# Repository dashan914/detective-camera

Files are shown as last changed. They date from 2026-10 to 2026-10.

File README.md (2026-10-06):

# 侦探相机 · Detective Camera

**把一张日常照片，变成一份可以带走的微型案卷。**

> **许可边界**：MIT 仅覆盖项目自有代码，CC BY 4.0 仅覆盖原创文档与外壳设计。仓库及历史中的试验配音、文学摘录和来源待确认的 ES8311 驱动，不属于这两项授权；其公开分发权尚未核实。公开可访问不代表这些素材可以自由复用、再分发或用于商业用途，请在使用前另行确认权利。第三方依赖保留原许可，详见 [许可声明](NOTICE.md)。

侦探相机是一台结合 AI、实体交互与数字制造的创作相机。按下快门后，它观察照片中的物件与细节，以真实可见的线索为起点，虚构一桩离奇、有趣、但符合现实因果的微型案件，再通过屏幕表情、侦探式语音和热敏打印，把这次观察变成一份纸质报告。

它不是用来判断现实真相的侦查设备，而是一个让人重新注意日常、参与叙事的创作搭档：一个杯子、一件衣服、一张工作台，都可能成为故事的开始。

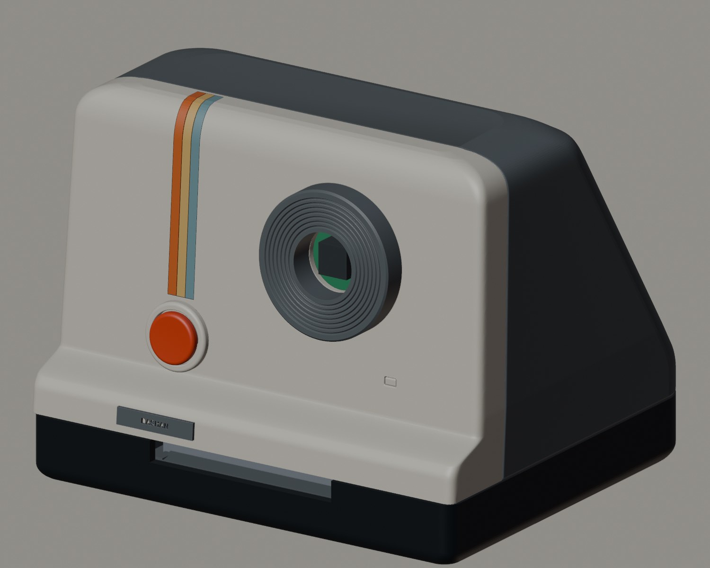
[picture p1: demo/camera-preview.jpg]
侦探相机外观


## 在线体验

[打开侦探相机交互演示](https://ai3dclass.cn/dashan/detective-camera/)

点击机身快门，体验侦探说话、顶部屏幕表情变化与案件出纸的过程；也可以拖动观察相机外观、打开字幕或阅读案卷。

网页使用固定案例展示交互，不连接实机，也不拍摄或上传观众的照片。真实相机则使用现场拍下的照片生成案件。

## 为什么做它

许多 AI 体验停留在输入框与屏幕里。我们想把它变成一个真实的小物件：能拿在手里、能表达反应，也能吐出一份纸质结果。让照片不只是被识别，而是成为一次有角色、有悬念、有反馈的互动。

创作者决定体验、硬件结构与叙事尺度，AI 辅助代码编写和方案迭代。项目关注的不是训练一个新的基础模型，而是如何把现成的模型能力、硬件和人的创意组织成完整体验。

## 一次使用会发生什么

1. **观察**：按下快门，拍摄眼前场景，记录物件、位置和状态。
2. **思考**：等待分析时，屏幕出现侦探表情，本地语音以观察和思考的口吻回应。
3. **推理**：以照片事实为依据设定案件，用一致的目标、行动和结果还原故事。
4. **出卷**：将照片、线索与推测打印成案卷；可选语音讲述同一个案件。

## 案卷 001｜衣服真正的主人

我发现衣服的肩膀上，总有两个鼓包。于是，我请它调查一下。没想到，它先调查了我。

现场线索：衣服肩部有两处凸起，位置正好对应衣架的两端。

> 衣架穿了它太久，这件衣服早就记住了衣架的样子。\
> 衣服真正的主人是衣架。\
> 而你，极有可能是个小偷。

第一次使用，它就把我从侦探变成了嫌疑人。

## 项目特色

- **照片事实与虚构故事分离**：先记录可见线索，再组织案情；不把虚构身份、动机说成已证实的事实。
- **把等待设计成表演**：语音、表情与打印状态配合，让分析延迟成为角色思考的一部分，而不是静止的加载页。
- **实体结果可以带走**：384 点热敏案卷把交互从屏幕延伸到纸上。
- **从软件到相机身体**：提供设备源码、后端、提示词、测试、网页演示和 V33 可编辑外壳/27 个 STL。

## 系统组成

ESP32-S3 负责拍照、快门、屏幕、语音播放和打印；Python 后端负责模型调用、结果校验、任务队列、票面与可选 TTS。模型输出文字/JSON，票面图片来自实拍照片的黑白处理，不是 AI 生成图片。

诗歌/文学匹配保留为附属功能，侦探相机是主线。

## 项目文件

| 目录 | 内容 |
| --- | --- |
| `competition/` | 项目简介、参赛展示脚本与证据清单 |
| `firmware/` | ESP32-S3 相机、快门、显示、音频、打印与配网源码 |
| `backend/` | 导演台、模型配置、案件生成/校验、渲染与测试 |
| `hardware/` | V33 装配、27 个 STL、结构预览与设计核验 |
| `demo/` | 三维交互、固件动画和固定案卷演示 |
| `voice_pack_12/` | 快门、思考与打印阶段的语音文件及命名说明 |
| `docs/`、`tools/` | 开发、接线、部署、验证与维护工具 |

## 制作与开发

- [本地开发指南](docs/DEVELOPMENT.md)：在自己的电脑上运行演示与导演台。
- [硬件与接线](docs/HARDWARE.md)、[原型物料清单](hardware/BOM.md)、[固件编译](firmware/README.md)。
- [外壳与打印文件](hardware/README.md)、[部署说明](docs/RESTORE.md)。
- [项目介绍](competition/PROJECT_BRIEF.md)、[展示指南](competition/DEMO_GUIDE.md)。

侦探相机用于互动创作，案情属于虚构，不用于现实侦查、身份判断或执法。实际硬件的验证范围见 [验证记录](docs/BACKUP_2026-10-04.md)。

## 许可与贡献

自有代码采用 [MIT](LICENSE)，原创文档与外壳设计采用 [CC BY 4.0](LICENSE-CONTENT.md)。第三方组件与素材的具体范围见 [许可声明](NOTICE.md)。

[贡献指南](CONTRIBUTING.md) · [隐私说明](docs/PRIVACY.md) · [安全说明](SECURITY.md)

维护署名：DASHAN / `dashan914`。

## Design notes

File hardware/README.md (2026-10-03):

# V33 外壳归档

自有 CAD/STL 和原创结构说明采用 CC BY 4.0，署名 `DASHAN (dashan914)`；第三方硬件/商标不因此获得授权。
物料索引与待实测项见 `BOM.md`。

`cad/DASHAN_V33.blend`：可编辑装配副本，保留 67 个网格物件（含辅助/试配样件）和 27 个打印件；从新场景导入几何，删除外部库记录、自定义元数据、图片与嵌入脚本。文件位置元数据改为中性相对名称并压缩保存，重新载入核验所有网格和变换与原稿一致。未改原装配或零件尺寸。使用 Blender 5.2.2 核验。

`stl/`：27 个独立零件，单位 mm。分别导入切片软件，按平台分盘，检查朝向、支撑和接触面。不要把网页 GLB 当作打印模型。

V33 基于 V30：只更换底座，正面看左侧靠后预留 USB-A 孔，右侧保持完整。
孔 13 × 6 mm、圆角 R1；孔中心距底面 11 mm、距最后端 13 mm。
`v33-check.json` 是原设计的开孔核验记录，不代表整机实物装配验收。
`previews/base-usb-left.png` 为开孔预览。

屏幕载架为 `33_LCD183_carrier.stl`，屏幕嵌入机身顶部开口。
接口模块固定座尚未设计，需实际试装；螺丝孔与螺丝长度也需按实物复核，不能将旧讨论视为全部验证完成。
USB 接口不能直接接电池电芯。电源接线说明见 `../docs/HARDWARE.md`。

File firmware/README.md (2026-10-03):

# 侦探相机固件

自有源码采用 MIT，但第三方库与未核实驱动不受该许可覆盖。
ESP32-audioI2S 3.4.7 为 GPL-3.0；分发与其组合的固件前需完成对应源码和许可证合规检查。
当前 ES8311 驱动的来源记录尚待补齐，不能直接把其许可声明为 MIT。详见 `../NOTICE.md`。

Open `PoetryCameraDirector/PoetryCameraDirector.ino` in Arduino IDE. The folder
retains its historical name to satisfy Arduino sketch naming requirements.
Install ESP32 Core 3.3.7 and ESP32-audioI2S 3.4.7 providing `Audio.h`.
The display uses the bundled driver. Wi-Fi and API secrets are not compiled in.
Select 16 MB Flash, OPI PSRAM (8 MB), USB CDC on boot, and the
`app3M_fat9M_16MB` partition scheme. Do not change partition layout on an
existing device without backing up its NVS and filesystem.

This sketch is the device side of the director-console workflow. It keeps Wi-Fi
and the backend URL on the ESP32, while all AI provider keys remain on the
server.

## First-time setup

1. Flash the sketch to the Waveshare ESP32-S3-CAM-OV5640.
2. Hold the board's `BOOT` button while restarting to force setup mode.
3. Join the `DASHAN-CAMERA-xxxx` Wi-Fi network with a phone.
4. Open `http://192.168.4.1`, select Wi-Fi, and enter the backend URL and device token.

If the saved Wi-Fi cannot be reached at startup, setup mode starts automatically.

## Implemented device contract

- `POST /api/device/heartbeat`
- `GET /api/device/jobs/next`
- `POST /api/device/jobs/{job_id}/complete`
- `POST /api/camera?job_id={job_id}` with a raw JPEG body

The camera pin map follows the supplied Waveshare board documentation. The
MY-628 uses UART0-compatible pins GPIO43 TX and GPIO44 RX at 9600 8N1.

## Fixed-layout printing

The server renders every ticket at exactly 384 dots using the bundled Zhuque
Fangsong and Courier Prime files. The ESP32 downloads the completed monochrome
job and sends it to MY-628 using the module vendor's documented `GS v 0`
horizontal raster command. UTF-8 text is never sent directly to the printer.

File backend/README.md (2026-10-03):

# 侦探相机后端与导演台

此后端以侦探案件为主，保留诗歌/文学匹配作为附属功能。网络服务使用 Python 标准库，票面图片通过 Pillow 渲染。AI 配置、任务队列、设备心跳和历史保存在本地 JSON 状态文件中，API Key 不会返回给网页或 ESP32，但状态文件本身可能含 Key，严禁提交。

## 启动

先复制 .env.example 为 .env，设置 CAMERA_SHARED_TOKEN 和 DASHAN_ADMIN_TOKEN。然后运行：

    python3 server.py

打开 http://127.0.0.1:8787/director。Basic Auth 用户名固定为 admin，密码为 DASHAN_ADMIN_TOKEN。

状态文件默认是 director_state.json，可用 DASHAN_DATA_FILE 指向其他位置。不要把服务端口公开到互联网。

## 导演台功能

- 侦探案件：实拍照片 → 可见线索 → 虚构案情 → 合理推测还原；字段与逻辑在本地校验。
- 手动案卷编辑、调查方向/叙事风格设置、384 点票面预览与打印。
- 可选案件语音：后端生成案件朗读；设备等待期间使用本地语音包。
- 相机参数：镜像、翻转、曝光、画质与按需低流量预览。
- 手动导演：输入 title / author / body / source / original / translation / date
- 拍照模式：将 photo_capture 请求加入 ESP32 轮询队列
- 固定票面契约：template_id / title / author / body / source / original / translation / date
- 结构化票面预览 HTML；预览与任务使用同一份 ticket
- 多套 OpenAI、DeepSeek 或自定义 OpenAI Chat Completions 兼容配置
- 接口地址、模型名、Key 可编辑；模型名不写死
- 测试连接、启用配置；网页只显示 Key 是否已保存
- 设备在线状态、任务状态和最近任务历史

## 管理接口

所有 /api/admin/* 需要 Basic Auth 或 X-Dashan-Admin。

- GET /api/admin/state
- GET /api/admin/providers
- GET /api/admin/history
- POST /api/admin/providers：{id,name,base_url,model,api_key}
- POST /api/admin/providers/activate：{id}
- POST /api/admin/providers/test：测试当前表单配置
- POST /api/admin/jobs：手动任务或 {mode:"photo"}，preview_only:true 只预览

## ESP32 接口

所有设备接口需要 X-Dashan-Token。

- POST /api/camera：原始 JPEG，返回 {ticket, preview_html}
- GET /api/device/jobs/next：返回 204，或 {job_id,type,ticket}
- GET /api/device/jobs/{job_id}/print-data：返回按 MY-628 官方 `GS v 0` 封装的 384 点光栅数据
- GET /api/device/jobs/{job_id}/audio-data：返回已生成的案件 MP3
- POST /api/device/jobs/{job_id}/complete：{status:"completed|failed|cancelled|awaiting_raster",detail}
- POST /api/device/heartbeat：接受 device_id / ip / rssi / firmware / printer / camera / mode

服务器使用朱雀仿宋和 Courier Prime 将 ticket 渲染成 384 点黑白位图，再按 MY-628 官方 `GS v 0` 命令发给设备。ESP32 不需要内置中文字库。

## 验证

    python3 -m unittest -v test_server.py test_detective.py test_detective_renderer.py test_case_voice.py

测试覆盖 Basic 鉴权、Key 脱敏、手动队列领取与完成、拍照任务预览、XSS 逃逸和设备心跳。

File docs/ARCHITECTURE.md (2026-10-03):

# 项目结构与体验

侦探相机不是现实鉴定工具。照片事实和虚构案情分开呈现，案卷注明「线索来自照片 · 案情纯属虚构」。

1. 快门：ESP32 拍摄 JPEG，立即播放本地观察语音。
2. 传输：设备带独立令牌上传照片到后端，导演台可显示状态与最近照片。
3. 推理：后端调用配置的模型，输出案件名、案情、照片线索、关键证据、推测还原和口述稿；本地检查字段及逻辑。
4. 等待：ESP32 根据实际耗时衔接侦探自言自语，屏幕进入思考表情；不强行截断正在说的句子。
5. 出案卷：后端把照片和文字渲染为 384 点位图，设备通过 UART 光栅打印。可选 TTS 生成同一案件的 MP3。

模型分析输出文字/JSON，不生成照片；票面照片来自实拍的黑白处理。TTS 失败有独立状态，不应使已排队打印失效。

`demo/` 是静态产品演示：使用固定示例案件和四个已生成音频，模拟流程，不调用 AI、不上传照片、不驱动真实打印机。屏幕动画源于固件绘图，3D 模型源于 V33 装配。

历史目录名含 Poetry，但当前核心体验为侦探相机；文学匹配及手动诗票仍保留。新部署首次配置时请在导演台选择侦探模式，勿直接恢复带 Key 的旧状态文件到 Git。

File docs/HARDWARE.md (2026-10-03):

# 接线与装配索引

以仓库内固件定义为准；接线前断电并核对丝印，不凭线色判断。

| 模块 | 当前固件连接 |
| --- | --- |
| 主板 | Waveshare ESP32-S3-CAM-OV5640，16 MB Flash / 8 MB OPI PSRAM |
| MY-628 热敏打印 | GPIO43 TX → 打印机 RX；GPIO44 RX 接返回信号前核对逻辑电平；9600 8N1，GND 共地 |
| I²C 共享总线 | SDA GPIO8 / SCL GPIO7，供相机、音频控制与扩展芯片使用 |
| MCP23017 快门 | 地址 0x27；PB0 输入上拉，按钮接 PB0 与 GND；按下为低电平，20 ms 消抖 |
| 扬声器 | 主板 SPK 座子（资源图编号 14），不是接到 GPIO14；由 ES8311 和板载功放驱动 |
| 1.83 英寸触摸 LCD | 固件 ST7789 驱动，284×240；MOSI 1 / CLK 5 / DC 3 / CS 6，板载扩展 IO 控制复位和背光 |

屏幕目前实现显示和表情，不据此声称触摸操作已验证。扩展板供电使用与 ESP32 兼容的 3.3 V 并共地；若地址不是 0x27，需要调整地址配置或固件，不能插上即假定工作。

电源：不要把 7.4 V 电池或降压后的 5 V 接到单节锂电 BAT 座子（资源图编号 15）。BAT 用于单节 3.7 V 锂电；5 V 稳压电源应走 USB 供电路径。打印机必须按其规格独立供电，不能从 ESP32 的 3V3 引脚供电。DTR 是流控信号，不是电源，勿直接接 3V3。

装配：前面板 → 镜头/相机载架 → 顶部屏幕载架 → 按钮导向和开关座 → 打印模块和纸轴 → 电池及底座 → 后壳。先干装检查排线弯曲半径、纸路、USB 开孔和螺丝长度，再紧固。当前归档没有可靠的最终螺丝 BOM，不编造数量/长度。

固件编译/配网见 `../firmware/README.md`，待机策略见 `../firmware/STANDBY.md`。

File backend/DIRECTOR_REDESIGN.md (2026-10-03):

# 侦探相机导演台候选版

项目主入口为侦探拍摄，手动导演用于编写虚构案件。诗歌和插画保留为附属创作。现有设备认证、相机设置、诗票渲染和打印协议保持兼容。

## 手动案件接口

复用 `POST /api/admin/jobs`（原管理员认证）。

- `mode: "manual"`，`output_mode: "detective"`
- `detective_result` 使用现有侦探 JSON 契约：案件名、3–4 条观察线索、关键证据、推测。
- `preview_only: true` 只生成预览，不加入队列、不调用 AI。
- 提交时生成 `raster_print`，复用现有 ESP32 位图打印流程。
- `print_image` 默认关闭；开启需同时设 `use_latest_photo: true`，服务端把最近照片处理并嵌入任务，避免后续拍照替换已排队图片。
- `show_key_evidence` 默认开启；`time`、`location` 可填写。

## 验收边界

使用隔离本机数据验证，不调用真实 AI、不触发真实设备打印。
接口测试覆盖手动预览、队列、字段校验、认证、照片快照及原诗歌流程。
生产部署须使用已核实的服务器访问方式；不得覆盖 `.env`、运行状态或照片。

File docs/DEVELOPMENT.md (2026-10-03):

# 本地开发指南

只想体验项目，可直接访问 [在线交互演示](https://ai3dclass.cn/dashan/detective-camera/)，不需要安装软件。

下面的命令用于在自己的电脑上启动项目。`127.0.0.1` 表示当前这台电脑，不是供其他人访问的在线地址；必须先运行相应服务，再在同一台电脑的浏览器打开。

## 网页演示

在仓库根目录执行：

```sh
cd demo
npm ci
node build.mjs
python3 -m http.server 8894 --bind 127.0.0.1
```

保持终端服务运行，在这台电脑上打开 `http://127.0.0.1:8894/`。网页使用固定案例，不连接设备，不调用模型 API。资源结构与测试方式见 [演示开发说明](../demo/README.md)。

## 导演台

在仓库根目录创建独立虚拟环境：

```sh
python3 -m venv .venv
. .venv/bin/activate
pip install -r requirements.txt
cp backend/.env.example backend/.env
```

在 `.env` 中填写独立的设备令牌、管理员密码和模型配置，再运行：

```sh
cd backend
DASHAN_HOST=127.0.0.1 python3 server.py
```

在同一台电脑上打开 `http://127.0.0.1:8787/director`。用户名为 `admin`，密码由 `DASHAN_ADMIN_TOKEN` 设置。首次使用请选择侦探模式。

上述回环地址用于本机开发，ESP32 无法通过它连接这台电脑。连接实机时，需要按 [部署说明](RESTORE.md) 配置设备能够访问的后端地址、鉴权与网络访问范围；不要把管理员密码或模型密钥写入网页。

真实照片处理需要支持当前请求格式的模型服务和使用者自己的凭据。案件配音为可选功能，外部服务的费用、延迟与可用性取决于服务提供方。

## 设备编译

设备使用 Arduino ESP32 Core 3.3.7 / ESP32-audioI2S 3.4.7，16 MB Flash、8 MB OPI PSRAM。接线与编译见 [硬件说明](HARDWARE.md) 和 [固件说明](../firmware/README.md)。工程名 `PoetryCameraDirector` 保留，以满足 Arduino 工程命名要求。

## 测试

在仓库根目录执行：

```sh
cd backend
python3 -m unittest -v test_server.py test_detective.py test_detective_renderer.py test_case_voice.py
```

测试使用合成图片与模拟服务，不上传私人照片、不调用真实 AI/TTS。验证记录见 [归档核验](BACKUP_2026-10-04.md)。完整实机复现及最终固定件、触摸操作仍需实物验收；打印完成事件表示数据发送完成，不代表纸张传感器确认。

## 维护与发布

密钥、设备状态、实拍照片与聊天记录不应提交。素材和依赖按各自许可使用，具体见 [许可声明](../NOTICE.md)、[隐私说明](PRIVACY.md) 和 [发布检查清单](RELEASE_CHECKLIST.md)。

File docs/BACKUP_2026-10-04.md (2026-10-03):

# 2026-10-04 私有归档核验

此文件记录最初私有备份的验证范围。后续参赛/开源准备已采用 MIT / CC BY 4.0，仓库仍为私有；公开前事项见 `RELEASE_CHECKLIST.md`，不要把此归档核验当作素材授权或完整硬件验收。

## 纳入本次归档

- 设备固件：相机、物理快门、显示、板载音频、打印、配网和待机源码，保留脱敏配置。
- 后端/导演台：模型设置、照片处理、案件结构与逻辑校验、票面渲染、可选案件朗读和测试。
- 网页：最新 V33 顶部嵌屏、固件原始动画、衣服案卷、清理后的三句推理语音、出纸同步与字幕布局。
- 机械：27 个独立 STL、完整可编辑装配副本、开孔预览与核验数据。
- 素材：当前 12 句语音及 report；网页只使用四个音频。保留第三方许可证。
- 文档：结构、硬件、恢复、隔离部署和隐私检查工具。

## 已完成验证

- 隐私检查：当前归档文件、已有 Git 历史及本地已知密钥比对，无发现；不输出匹配值。
- 后端：48 项测试通过，使用合成图片/模拟服务，未调用真实模型或语音 API。
- 网页：锁定依赖安装与独立构建成功；浏览器检查无 JS 错误或资源失败；完整案件语音与出纸同步；字幕在 320–1440 px 及减少动态效果下正常。
- CAD：Blender 5.2.2 重开脱敏压缩文件，67 个网格的顶点、面和变换与原稿逐一一致；27 个打印件齐全；没有外部库、图片或嵌入脚本。
- MP3：17 个当前归档/演示音频全部解码检查通过，仅有编码器标签。
- 图片：删除 CAD 预览的路径/EXIF 附带信息；网页 JPEG 无损移除 EXIF/Photoshop 元数据，不改变压缩图像内容。

此次未刷写 ESP32、未调用付费接口、未修改在线服务或服务器其他项目；没有进行新的整机实物装配/螺丝验收。备份不包含生产配置，恢复时需重新填写密钥与配网信息。

## 同日参赛/开源准备复核

- 新增参赛简介、演示指南、原型 BOM、贡献/安全说明、MIT 与 CC BY 4.0 范围声明。
- 再次运行 48 项后端测试，全部通过；新增 6 项公开包检查测试，全部通过。
- 核对 14 份主要说明的相对文件链接，无失效目标。
- 当前文件与历史隐私扫描无发现。发布预检仍明确返回未就绪：配音/视觉授权、驱动来源、文学库替代、固件分发合规、干净环境复现、BOM 验收和比赛规则需继续核对。
- 发布检查为只读工具，不导出、不发布；当前工作只备份到私有仓库，不将旧素材或旧历史视为可公开内容。

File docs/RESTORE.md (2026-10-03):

# 恢复与隔离部署

## 取回与核验

通过拥有权限的 GitHub 账号克隆私有仓库，记录提交号。运行 `python3 tools/privacy_check.py --history` 和 `python3 tools/backup_manifest.py`；清单只记录仓库相对路径、字节数和 SHA-256，不含密钥。不要将生产 `.env` 或设备镜像加入仓库。

## 后端

创建独立虚拟环境，安装根目录 `requirements.txt`，复制 `backend/.env.example` 为 `backend/.env`；用不同随机值配置设备令牌和管理员密码，设置模型地址/ID/API Key。案件配音为可选功能，另外填写自己的音色 ID。禁止复用别的项目密钥。

后端默认新状态保留历史兼容模式，首次登录后选择侦探模式并保存。重新配网设备，填写自己的后端地址及相同设备令牌。备份版不硬编码旧服务器地址、不自动迁移现有设备。

```sh
cd backend
python3 -m unittest -v test_server.py test_detective.py test_detective_renderer.py test_case_voice.py
DASHAN_HOST=127.0.0.1 python3 server.py
```

测试使用合成图片及假响应，不发送私人照片或请求真实 AI/TTS。先验证管理员鉴权、设备心跳，再单独授权实拍测试。

## 与服务器其他项目隔离

部署到新的目录、专用服务用户、独立虚拟环境、独立 systemd 服务名、独立数据目录和空闲端口。示例服务在 `../deploy/detective-camera.service.example`，仅为模板，不会自动安装或启动。确认 8788 未占用后再使用；不要修改现有服务或其端口。

生产密钥由本机权限 0600 的环境文件提供；数据目录包括带 Key 的状态 JSON、照片和动态音频，不对外公开。HTTPS 反向代理只映射预期的 API/导演台，限制请求大小；静态网页只能发布 `demo/` 发布清单，绝不能公开项目根目录或 backend。

切换前备份现有目录/链接，校验新服务健康，再只切换侦探相机自己的入口；不停止其他项目。回滚只恢复自己的旧入口，不删除共享目录、不覆盖整个站点。

## 静态网页

在 `demo/` 执行 `npm ci`、`node build.mjs`。发布 `index.html`、`detective.css`、`detective.js`、`DASHAN_V33.glb`、`camera-preview.jpg`、字体及许可、`screen-frames/`、`draco/` 和四个使用中的 `audio/` 文件。源码脚本不必发布；资源路径可用于 `/dashan/detective-camera/` 子路径。`legacy-preview-redirect.html` 是可选旧入口跳转模板。

## 设备和外壳

按 `firmware/README.md` 安装匹配的 Arduino Core/库并编译。不要盲目擦除整盘或改分区，否则会丢失 NVS/语音文件。语音文件使用 `voice_pack_12/filesystem/voice/`，目前固件读取 FFat，复制到 SD 卡不会自动生效。刷写前确认设备实际分区表；本仓库不保存含私密数据的整盘镜像。

Blender 源在 `hardware/cad/`，打印件在 `hardware/stl/`；每件尺寸、支撑和硬件试装需重新检查。网页 GLB 只展示，不用于切片。

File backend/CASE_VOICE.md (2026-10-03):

# Case narration candidate — 2026-09-16

This adds narration without replacing the 12 preset voices in `/voice/`.

## Flow

Photo -> detective result -> existing print job. A separate worker sends only
the subject, setup and conclusion to Fish Audio (`s2.1-pro-free`, 64 kbps MP3).
It never sends the photograph, device token or AI provider credentials.
There is no paid-model fallback and no automatic TTS retry.

An authenticated `case_audio` job becomes eligible after its print job reports
completed and the device advertises top-level `narration: "mp3-v1"`.
The device downloads at most 1 MiB into a separate temporary FFat file, waits
for the current preset voice to finish, then plays the case. The application
partition alone is updated; no filesystem or NVS image is flashed.

TTS failure does not block printing. Undelivered audio expires after 10 minutes.
Files are retained only for audio jobs in the bounded 100-job history.
ESP32 print completion means raster data was sent, not physical paper sensing.
Audio completion means the decoder stopped after playback, not microphone-based
confirmation that the speaker was audible.

## Configuration and testing

Server-only `.env`: `FISH_VOICE_ENABLED=1`, `FISH_API_KEY`, `FISH_REFERENCE_ID`.
Configure these values on the deployment host and protect `.env` with mode
0600. Never put keys or personal voice reference IDs in firmware or Git.

`POST /api/admin/narration/test` (admin authenticated) synthesizes the latest
completed printed detective case without taking another photo or printing again.
It rejects an active narration to avoid accidental duplicate requests.

`GET /api/device/jobs/{id}/audio-data` requires the existing device token.

Tests: `python3 -m unittest test_case_voice test_detective test_detective_renderer test_server`.

## Recovery

Back up your own application before changing firmware. Disable narration by
setting `FISH_VOICE_ENABLED=0` and restarting only your camera service.
Do not erase flash or overwrite the FFat/NVS partitions during recovery.

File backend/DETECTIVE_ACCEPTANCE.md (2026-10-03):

# 侦探相机候选版本验收

## 不变的硬件与原功能

沿用 `/api/camera` JPEG 上传、现有 AI provider、PNG 预览、384 点 ESC/POS 输出及设备打印流程。原始照片用于视觉分析，打印图单独处理；不使用 AI 重绘。

照片执行 EXIF 纠正、等比例缩入 336×252、灰度、温和对比度及暗部调整、轻微锐化、Floyd–Steinberg 黑白抖动。保留画面全部内容，余量白色填充。每张票保存自己的处理图，不从“最新照片”反查。

字体复用现有字体加载函数和资产，不引入本地绝对字体路径。案件模板的 24 像素边距不影响诗票原边距。

## 必须区分的验收

自动测试只能证明结构、接口和指定回归样例；不能证明线索在真实照片中成立，也不能证明实物热敏效果。规则只能拦截部分不当表达，不能作为语义安全或真实性保证。

发布前需使用 30～50 张用户授权的真实日常照片测试。不要用模型合成照片代替，不要把未运行案例填为通过。

建议至少覆盖：单人、多人、无人街景、室内、餐厅、办公室、卧室、风景、建筑、宠物、桌面、单件物品、食物、车辆、旅行、极简、复杂、凌乱、普通日常和玻璃反射；同类至少有不同构图。

逐图记录：

- 文件编号、场景类别、指定视角、最终视角及风格。
- 每条线索在原图中的可见依据，是否存在臆造或重复模板。
- 推理是否被多个线索支持，弱证据是否切换为 discovery。
- 是否涉及身份、健康、心理或私人关系猜测。
- 原图边缘是否保留、打印黑白图是否仍可辨识所述证据。
- 图片及文字是否越界、长句是否完整、预览和实物输出是否相符。

极简照片无法给出三条可靠线索时允许明确失败，不允许以格式要求迫使模型补造证据。外部视觉调用可能计费；运行真实评测时使用用户确认的 provider 和照片集。

## 回归基线

源码恢复点：`4544fea`。不含运行配置、密钥、图片和字体资产。

`test_detective_renderer.py` 记录了改动前两份诗票 PNG 与 ESC/POS SHA-256，可确认相同环境下这两个样例的输出未变。

本次开发不自动部署、不发送实体打印、不调用付费视觉接口。真实照片评测和实体打印需要单独验收。

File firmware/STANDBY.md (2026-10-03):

# Shutter standby

PB0 on MCP23017 at 0x27 remains the physical shutter. A debounced release
under two seconds takes a photo. A two-second hold queues standby or wake.
A dedicated task samples the button every 5ms with 20ms debounce, independent
of camera preview and network requests; loop() consumes queued actions.
MCP transactions and display-expander writes share an I2C mutex. A held button
at boot must be released before use.

Standby is software idle, not power-off or ESP32 deep sleep. It blanks the
panel, disables backlight/amplifier while preserving EXIO5 BAT_EN, stops audio,
deinitializes camera capture and turns Wi-Fi off. Wake restarts the ESP32.
Presses during active cases, printing or audio are rejected, not deferred.

USB maintenance commands: S enters standby; R wakes while in standby.
Serial verification passed for enter/wake, camera init 0x0 and preview without
errors. Physical button verification is still required after the sampling fix.

Application-only rollback image is build-standby/before-standby-app.bin,
read from flash address 0x10000 before the initial standby update. Preserve
NVS, partition table and FFat when updating the application.

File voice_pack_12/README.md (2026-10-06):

# 侦探相机预设语音

**当前 MP3 为历史试验素材，其公开分发权尚未核实，不在项目 MIT / CC BY 4.0 许可范围内。仓库可访问不表示允许自由复用、再分发或商用。**
参赛和公开演示需使用原创或已明确许可的声音，不能把第三方真人/角色音色当作可自由再分发素材。此目录保留阶段与命名约定，方便替换。

`filesystem/voice/` 内是固件使用的 MP3 文件：

- `01–04_shutter.mp3`：拍摄后开始观察。
- `05–08_wait.mp3`：等待期间的侦探式思考。
- `09–12_printing.mp3`：生成完成、准备出卷。
- `report.mp3`：存在时优先用于出报告阶段。

此仓库只保存音频，不包含设备 Flash 镜像。不要把旧版整盘镜像刷进新设备；
应按固件实际分区配置构建文件系统，或在固件支持的情况下直接复制到存储卡。
这份固件当前通过 FFat 访问 `/voice/`，仅复制到 SD 卡不会自动生效。

USB 串口发送 `w` 可执行预设语音自测，不触发拍摄、AI 或打印。
发送 `v` 可在预设流程之后继续播放已保存的案件朗读。

替换时保持上述文件名，核验解码、采样率、音量和句尾，分别测试快门、等待、出卷阶段；不要用截断对白来适配固定等待时间。复用项目时建议使用原创/明确许可配音或经验证的无声音版本，详见 `../docs/RELEASE_CHECKLIST.md`。

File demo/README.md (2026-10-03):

# 侦探相机网页演示

[打开在线交互演示](https://ai3dclass.cn/dashan/detective-camera/)

静态、可独立部署的演示，不连接设备，不采集或上传观众照片，不调用 AI。
示例案件用于展示真实产品的交互顺序：快门、观察语音、屏幕思考表情、形成推测、打印案卷。
点击机身快门或按钮均可开始；提供声音开关、字幕、跳过等待、阅读案卷和减少动态效果支持。

## 在自己的电脑上运行

以下命令在本目录执行：

```sh
npm ci
node build.mjs
python3 -m http.server 8894 --bind 127.0.0.1
```

启动服务后，在同一台电脑的浏览器打开 `http://127.0.0.1:8894/`。这是本机开发地址，不是在线演示入口。

发布文件：`index.html`、`style.css`、`detective.css`、`detective.js`、
`DASHAN_V33.glb`、`CourierPrime-Regular.ttf`、`CourierPrime-LICENSE.txt`、
`screen-frames/`、`draco/` 与 `audio/`。三维模型由现有 V33 装配导出，屏幕嵌在实际顶部开口，
未额外添加屏幕支架。网页 GLB 用于可视化，不作为打印文件。

屏幕动画由 `generate_screen_frames.py` 直接编译固件 `DetectiveDisplay.cpp` 绘图函数生成，
保留原有侦探造型、眨眼、嘴型、观察/思考/打印状态。待命展示固件取景框，
不嵌入私人相机实时照片；减少动态效果时使用静态帧。

`index.template.html` 为页面源文件；`viewer.js` 与 `ritual.js` 为三维交互源码。
`detective.js` 保存项目介绍和示例案卷；`build.mjs` 输出内嵌三维脚本的页面。
快门与等待语音由使用者提供；`audio/clothes-case-clean.mp3` 是通过项目已有朗读 API
生成的已确认三句推理，约 8.93 秒。已去除中间非对白人声，保留自然停顿。
出纸进度跟随音频，字幕与纸条使用同一份推理文字；API Key 和音色 ID 不进入网页。

演示引用四个音频（`01_shutter.mp3`、`05_wait.mp3`、`report.mp3`、
`clothes-case-clean.mp3`），其授权范围见 [许可声明](../NOTICE.md)，不属于项目 MIT / CC BY 4.0 授权。
部署时只映射演示所需的静态资源，不要把整个仓库或后端目录映射为静态站点。
部署在子路径时保留相对资源路径，详见 `../docs/RESTORE.md`。

## 可选再生成

`generate_case_narration.py` 从 `--backend-dir` 指定的本地 `.env` 读取已有密钥与音色配置，
只生成已确认的整段或单句，不创建音色。运行会调用外部服务；备份、构建和测试不会自动调用。
`export_assembly.py` 从仓库内脱敏装配导出网页 GLB，需 Blender 并关闭自动执行脚本。
`generate_screen_frames.py` 从固件绘图函数生成 288 帧，需 Python、Pillow 与 clang++。

## 浏览器测试

安装 Playwright 后，启动本地静态服务器，再运行 `node verify.cjs`。
支持 `PLAYWRIGHT_MODULE`、`CHROME_PATH`、`DEMO_URL` 环境变量。
测试覆盖顶部实际屏幕、27 件模型、完整朗读与出纸同步、字幕边界、移动端和减少动态效果。

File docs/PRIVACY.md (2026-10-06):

# 隐私与公开版本边界

本项目公开展示源码、工程结构与实现过程。GitHub 公开不包含密钥、私人运行数据或聊天记录，也不表示全部素材已获分发授权。许可范围与未核实事项见 `../NOTICE.md`。仓库可见性调整不启用 Pages、不改变线上站点。

保留：源代码、提示词与字段结构、合成测试、静态展示、脱敏 CAD、27 个 STL、第三方声明与复现文档。仓库及历史保留试验语音、文学附属库和来源待确认的驱动，但它们不属于项目自有 MIT / CC BY 4.0 授权范围。

排除：`.env`、Wi-Fi 配置、服务器私钥/IP、令牌/密码/API Key、私人音色 ID、聊天记录、原始实拍照片、导演台历史、动态案件音频、源配音/调试录音、设备 Flash/NVS/FFat 镜像和构建缓存。

密钥与生产状态仍在原环境中，整理不删除使用者原资料。恢复需重新填写配置；GitHub 不能替代密钥管理器或设备数据备份。

## 真实照片如何流转

真实设备会把 JPEG 上传至所配置的后端，再发送到配置的模型服务。后端保留最近照片、预览、任务状态与可选语音；不是「全部在设备本地计算」。只有经授权的照片才能用于 API 测试、演示视频或提交比赛。不得因去掉文件名/EXIF 就认为人像、住址和屏幕内容已经匿名。

## 检查工具

`tools/privacy_check.py` 可检查当前文件、Git 历史和本地已知密钥，只输出文件名及分类，不输出匹配内容。自动扫描不能代替照片、声音和权利的人工确认。

```sh
python3 tools/privacy_check.py --history
python3 tools/privacy_check.py --history --secret-env /path/to/private/.env
python3 tools/backup_manifest.py
```

## 公开可访问不等于素材可自由复用

历史提交包含试验 MP3。本仓库保留历史并标注授权边界，不将这些文件认定为已获公开分发许可。`tools/public_release_check.py` 用于核对一个排除未核实素材的候选发布包，仍会报告素材授权、复现与验收待办；不能因仓库已公开而将这些待办标为完成。详见 `RELEASE_CHECKLIST.md`。

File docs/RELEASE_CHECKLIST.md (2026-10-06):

# 公开与参赛前检查

仓库按维护者指令公开并保留历史，授权边界已标注；本清单记录仍未完成的素材核验与复现验收，不因可见性变化而自动完成。不启用 Pages、不发布固件二进制、不更新在线网站。

## 内容与授权

- [x] 自有代码 MIT；原创文档/外壳 CC BY 4.0，明确第三方例外。
- [x] 项目介绍改为互动创作原型，不声称现实侦查或自研基础模型。
- [x] 区分实机、静态演示和预设脚本，不虚构速度/成功率。
- [ ] 替换现有试验 MP3 为原创/明确许可声音，或制作可核验无声音演示。
- [ ] 复核屏幕角色的原创性与显示素材，不以第三方角色为项目授权卖点。
- [ ] 确认 ES8311 驱动来源和许可，保留必要版权声明。
- [ ] 文学附属库补齐作品/翻译来源，或公开包使用不含旧摘录的库。
- [ ] 如提供固件二进制，完成音频库 GPL-3.0 及工具链第三方合规检查、对应源码说明。

## 复现与证据

- [x] 设备、后端、网页、外壳和验证文档已分类。
- [x] 基于 2026-10-04 原型通过 48 项后端测试及网页检查。
- [ ] 从空白环境按文档完整复现一次；记录首次构建和实机流程。
- [ ] 补全螺丝、电源、线材和扬声器 BOM，完成打印/装配验收。
- [ ] 录制无隐私、使用合规素材的实机演示，注明真实等待时间。
- [ ] 提供具体比赛规则后核对署名、AI 使用声明、字数、视频、开放时间和提交要求。

## 后续完整发布包

1. 当前仓库及历史含试验配音等授权待核实素材，均不纳入项目自有开源许可。另行制作可完整复用的发布包时，保留历史归档并排除未核实素材。
2. 运行 `python3 tools/privacy_check.py --history` 与 `python3 tools/public_release_check.py`。后一项会报告授权/复现待办，不把隐私扫描当授权确认。
3. 用核准清单导出新的文件树；不携带 `.git`、MP3、私人运行数据或当前文学库。未确认许可的驱动不得悄悄混入。
4. 完成声音/文学库替代和驱动核验，重新构建、测试并记录新版本。单纯排除这些文件会影响复现，不能把残缺包称作完整版本。
5. 创建 Release、分发固件二进制或上线新版属于独立操作，需要维护者另行明确指令。

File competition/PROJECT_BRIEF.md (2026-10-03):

# 侦探相机：把日常变成一场推理游戏

## 一句话简介

一台会观察、会思考、会说话，也会吐出纸质案卷的 AI 互动创作相机。

## 报名摘要

侦探相机以真实照片为线索，创作离奇但符合现实因果的微型案件。用户按下快门后，相机记录场景中的物件与细节，在等待分析时用屏幕表情和侦探式自言自语回应，最后把案情、现场线索和推测还原打印成可带走的报告。项目将 ESP32-S3、模型服务、音频、热敏打印与 3D 打印外壳连接成完整体验，探索 AI 如何从聊天窗口走向可触摸、可参与的创作搭档。

## 完整介绍

我们看见一件衣服，通常只会判断它是什么；侦探相机则试着追问：这里能发生什么故事？它不调查现实中的犯罪，不给人贴上身份或性格标签，而是把普通场景转化成一场轻盈的叙事游戏。

使用者只需按下快门。照片中的形状、位置和状态构成真实线索，模型以此设定一个有趣的异常，再让人物的目标、行动与结果形成连贯的经过。屏幕、声音和出纸不是装饰，而是同一流程的反馈：拍到了，正在想，故事有了，报告可以拿走了。

等待也是设计的一部分。分析时，相机像一个认真办案又有点古怪的搭档，自言自语、停顿、换表情。结果落在纸上，让观众不必盯着手机就能参与，还可以把这次体验带走。

项目由现成模型能力与常见硬件构成，没有声称自研基础模型。创作者提出体验、选型、结构与叙事标准，并使用 AI 辅助编程和迭代。拟开放自有源码、复现文档及外壳设计，希望让更多人把抽象创意做成真实物件。

## 示例案卷 001｜衣服真正的主人

**案情**：我发现衣服的肩膀上，总有两个鼓包。于是，我请它调查一下。没想到，它先调查了我。

**现场线索**：衣服肩部有两处凸起，位置正好对应衣架的两端。

**侦探推测**：衣架穿了它太久，这件衣服早就记住了衣架的样子。衣服真正的主人是衣架。而你，极有可能是个小偷。

第一次使用，它就把我从侦探变成了嫌疑人。

这是创作示例，不是现实指控，也不是故事质量的量化评测。

## 创作贡献

1. 把「事实记录」与「故事虚构」分开，给生成内容明确的真实性边界。
2. 用角色反应组织等待、反馈和打印，让模型延迟进入交互节奏。
3. 将模型、设备、音频、票据和外壳整合为可携带的实体原型。
4. 将源码、结构和测试整理为可继续修改的项目，而不仅是一段效果视频。

以上为本项目的设计取向，不作「首创」「领先」或对其他作品的性能比较。

## 进一步了解

[在线交互演示](https://ai3dclass.cn/dashan/detective-camera/) · [系统与项目文件](../README.md) · [展示指南](DEMO_GUIDE.md)

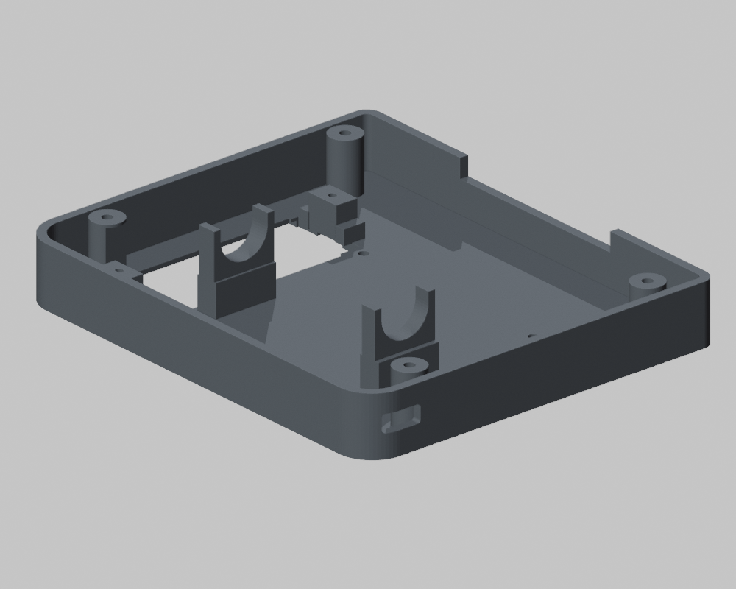
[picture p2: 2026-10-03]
hardware/previews/base-usb-left.png

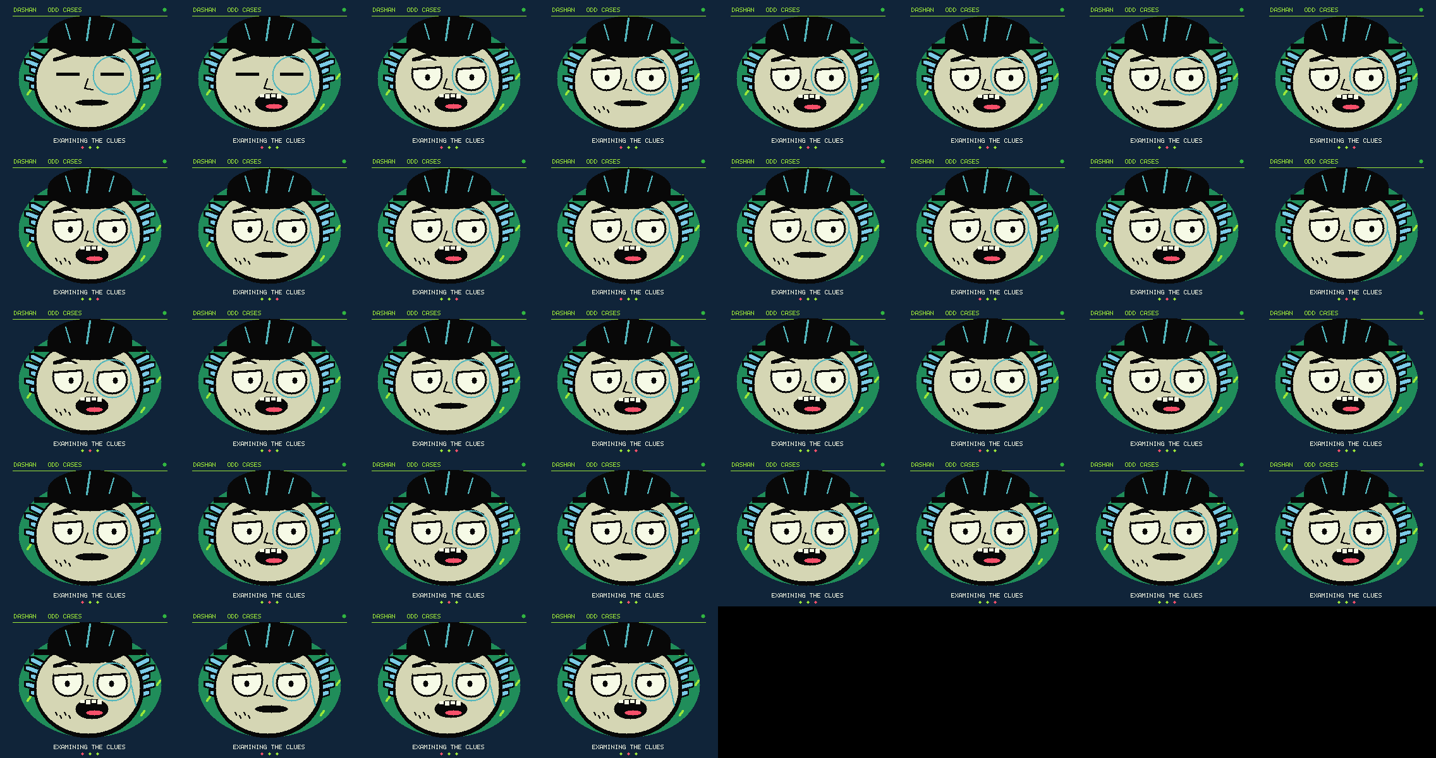
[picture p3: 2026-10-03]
demo/screen-frames/deducing-talking.png

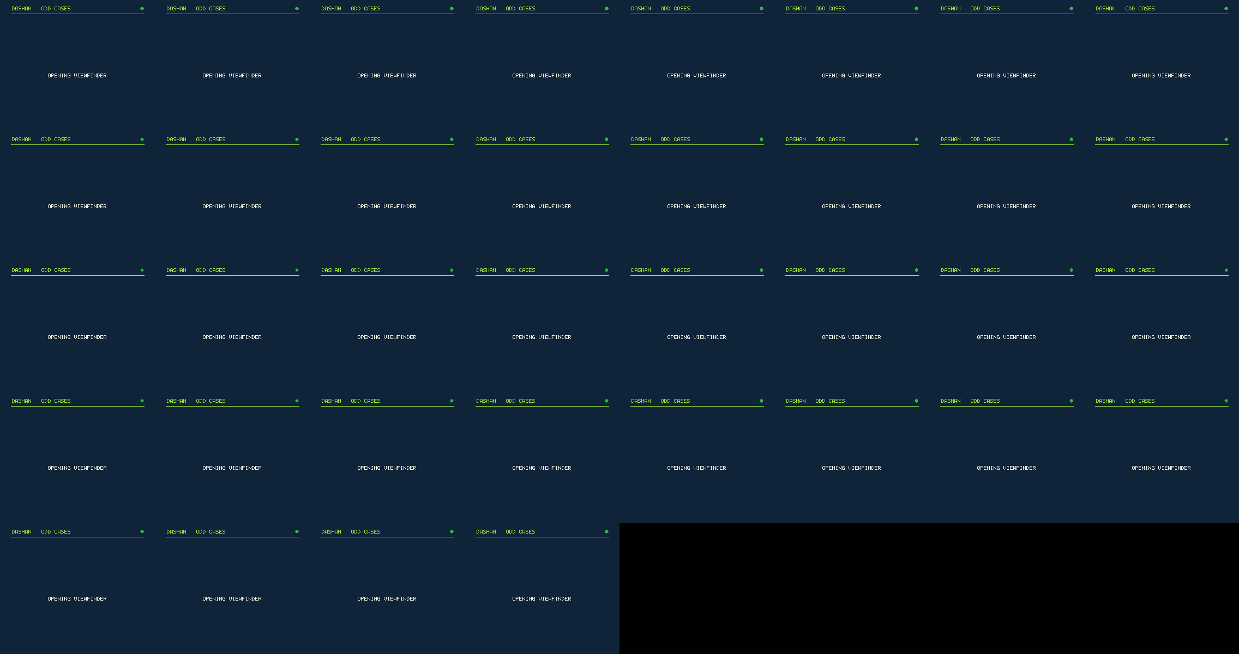
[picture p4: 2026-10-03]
demo/screen-frames/ready-silent.png

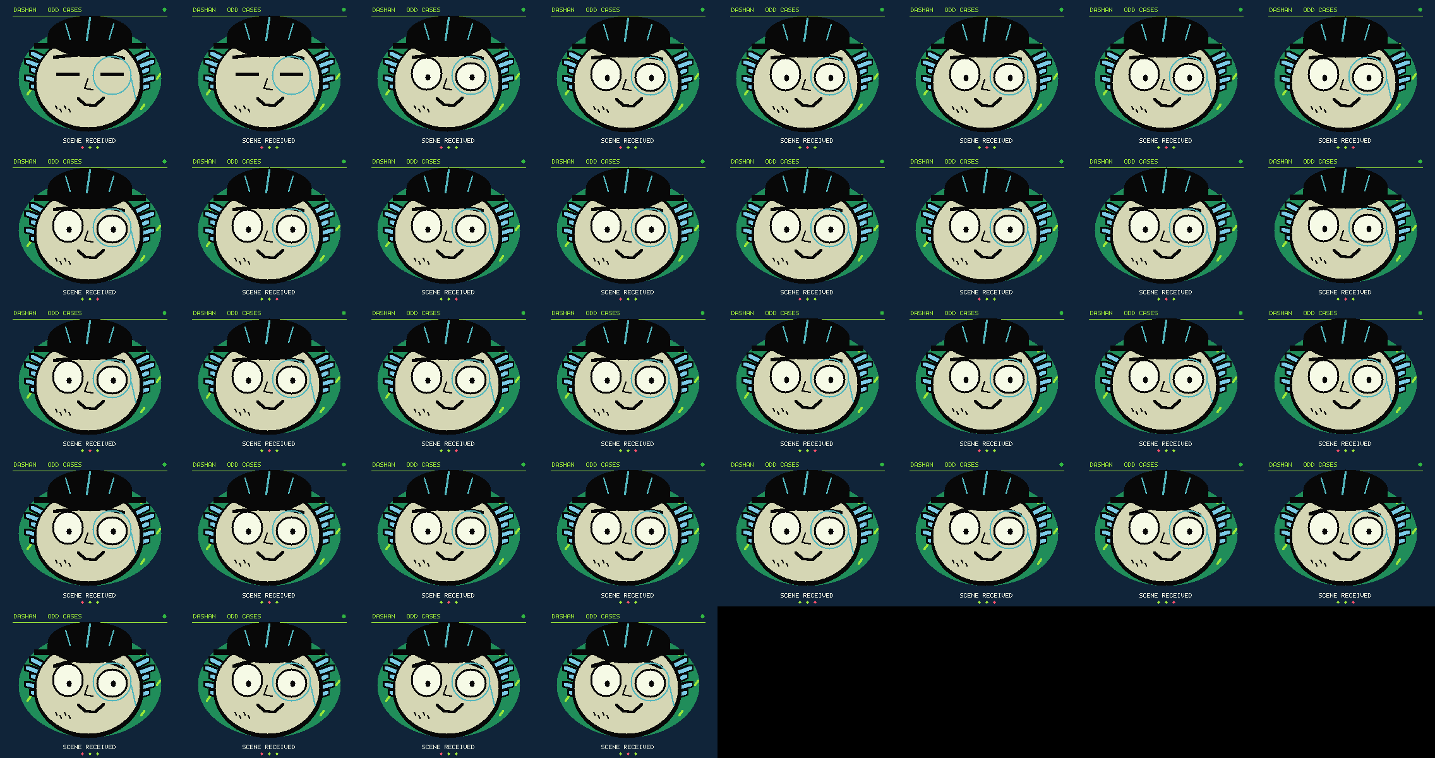
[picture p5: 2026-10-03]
demo/screen-frames/capturing-silent.png

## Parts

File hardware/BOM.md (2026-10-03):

# 原型物料清单

下列为当前方案索引，不是已完成采购验收的生产 BOM。价格随供应渠道变化，未填虚构总成本。

| 物料 | 数量 | 用途与说明 |
| --- | --- | --- |
| Waveshare ESP32-S3-CAM-OV5640 | 1 | 主控、相机、板载音频和扩展 IO；16 MB Flash / 8 MB PSRAM |
| 1.83 英寸 Touch LCD Module | 1 | 顶部显示，固件逻辑画面 284×240；触摸操作尚未验收 |
| MY-628 热敏打印模块 | 1 | UART 光栅打印，384 点；纸张与供电规格以实际模块为准 |
| MCP23017 IO 扩展板 | 1 | 实体快门输入，当前固件地址 0x27，按钮接 PB0/GND |
| 常开瞬时按钮 | 1 | 快门；四脚按键需确认常通脚对，不用电源直接接信号脚 |
| 匹配板载功放的扬声器 | 1 | SPK 座子输出；实际阻抗/功率需核对物料型号 |
| 合规 USB 5 V 电源及线材 | 1 套 | 首次桌面复现推荐的主板供电路径 |
| 匹配打印模块的独立电源 | 1 套 | 不从 ESP32 3V3 给打印机供电，共地并核对信号电平 |
| V33 外壳打印件 | 27 件 | 材料、壁厚和切片参数需随打印机试验 |
| 接线、连接器、热敏纸与固定件 | 按实物 | 线序和规格需核对，不按线色推断 |
| 便携电池/稳压组件 | 可选 | 待整理最终安全接线；单节 BAT 座子不可接 7.4 V 或 5 V |

## 待补实测项

- 最终螺丝类型、数量、长度，以及孔径/装配公差的实物验证。
- 完整打印模块、电源、扬声器和连接线的采购型号。
- 电池方案、满负载电压/电流、连续打印与续航测试。
- 支撑、打印方向、首件装配与纸路可靠性记录。

这些空缺是公开复现前的待办，不以「已经验证」描述。接线安全见 `../docs/HARDWARE.md`。

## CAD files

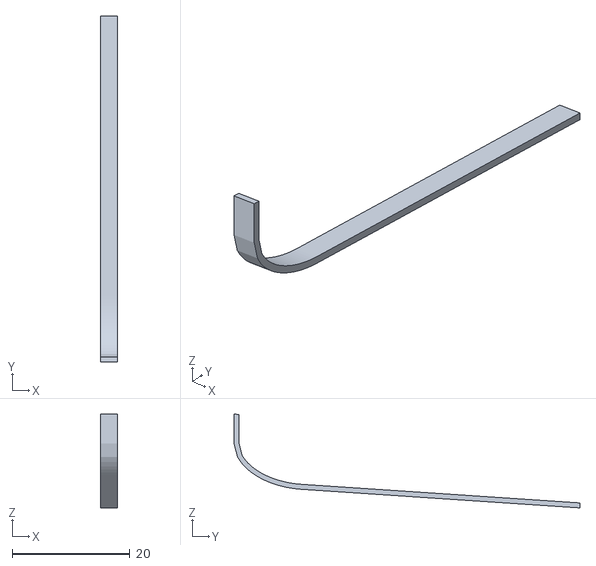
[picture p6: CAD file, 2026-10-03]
hardware/stl/10_L_inlay_1.stl
2.85 x 58.7 x 15.9

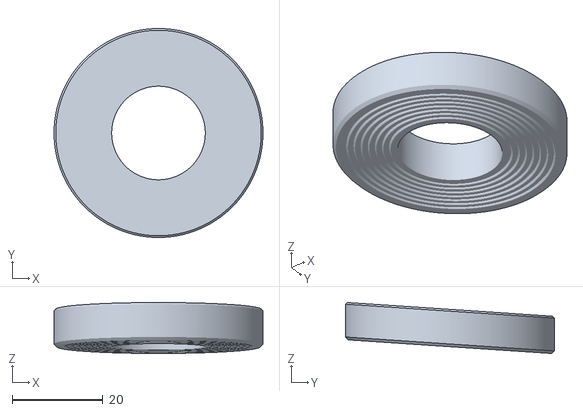
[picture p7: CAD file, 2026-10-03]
hardware/stl/12_Lens_trim.stl
46.0 x 46.0 x 11.2

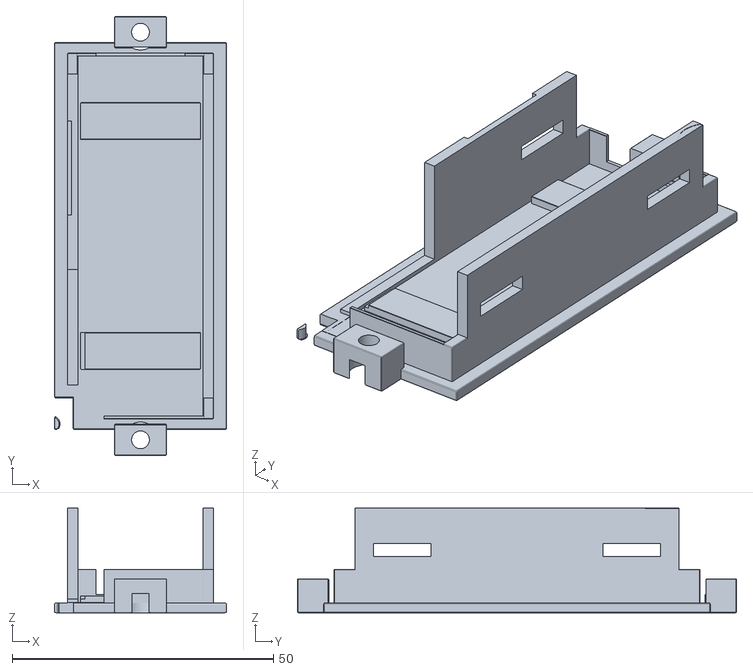
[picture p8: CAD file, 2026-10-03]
hardware/stl/14_Battery_hatch.stl
33.0 x 84.0 x 20.0

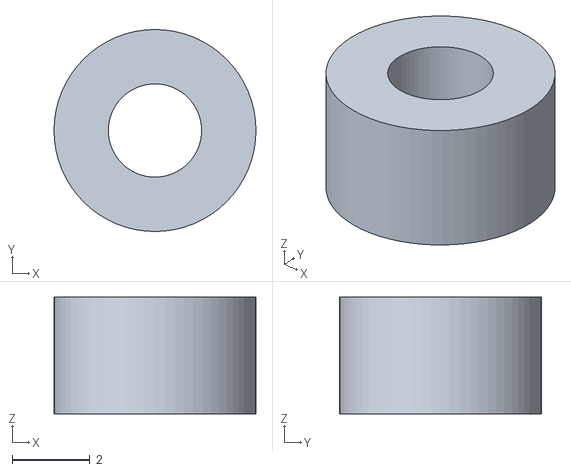
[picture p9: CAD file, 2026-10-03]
hardware/stl/26_Optical_spacer_3mm_6.7_91.3.stl
5.20 x 5.20 x 3.00

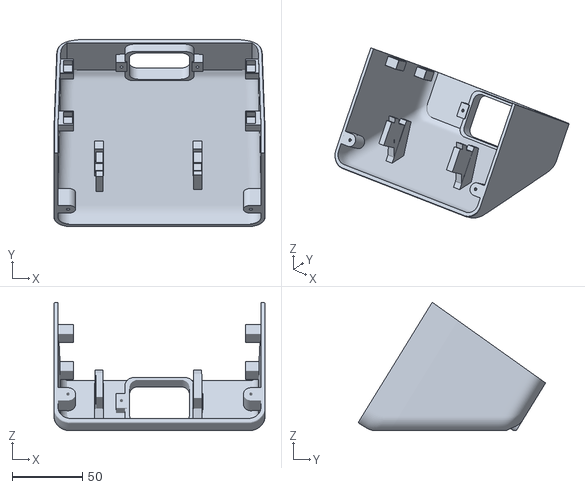
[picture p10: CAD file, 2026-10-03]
hardware/stl/02_Rear_housing.stl
150.0 x 133.1 x 91.3

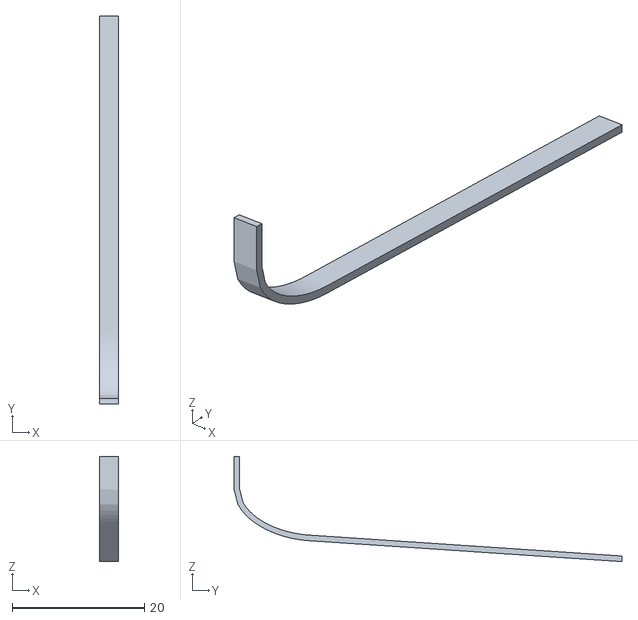
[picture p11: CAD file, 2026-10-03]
hardware/stl/10_L_inlay_2.stl
2.85 x 58.7 x 15.9

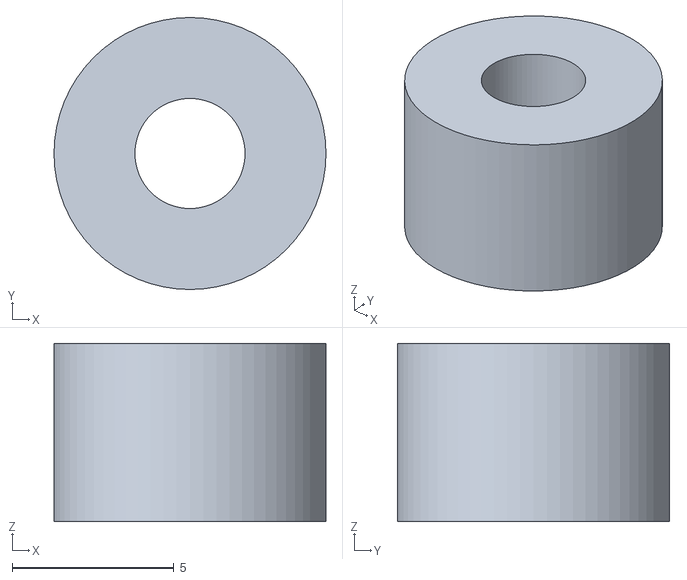
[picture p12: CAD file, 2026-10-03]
hardware/stl/21_Camera_spacer_upper.stl
8.40 x 8.40 x 5.50

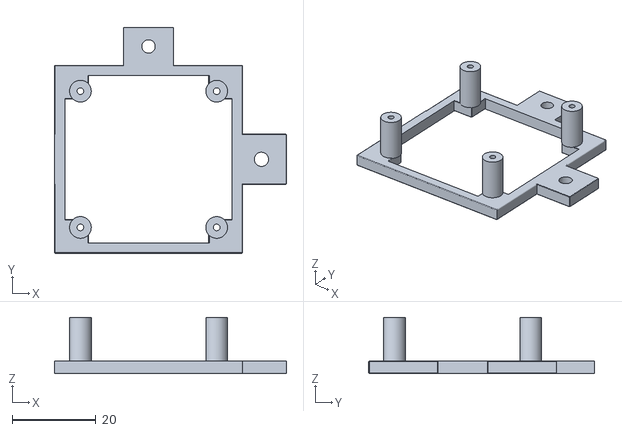
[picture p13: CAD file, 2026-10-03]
hardware/stl/20_Camera_carrier.stl
55.5 x 54.0 x 13.4

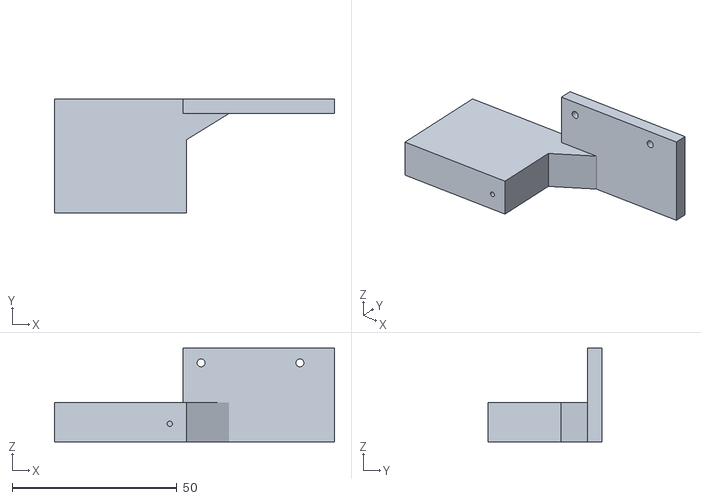
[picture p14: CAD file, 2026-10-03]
hardware/stl/32_Printer_right_integral.stl
85.0 x 34.6 x 28.5

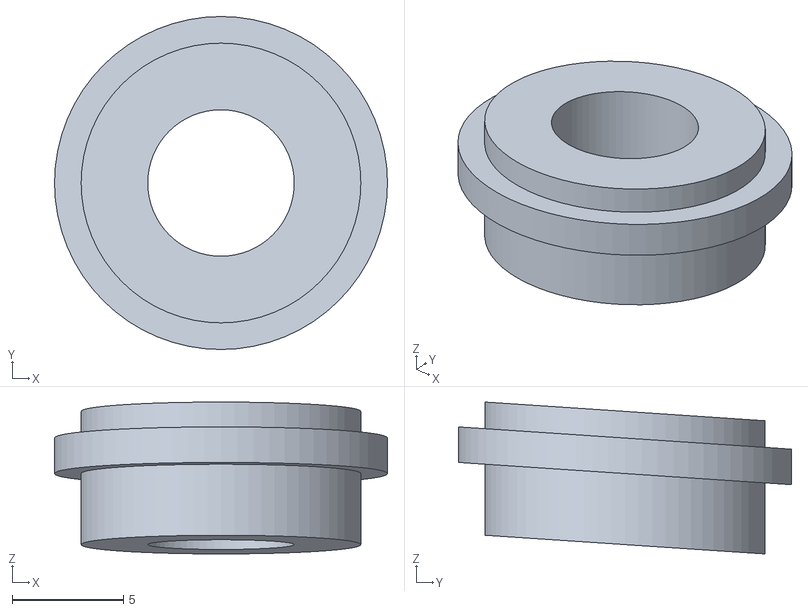
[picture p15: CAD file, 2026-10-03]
hardware/stl/07_Shutter_guide.stl
15.0 x 15.0 x 6.84

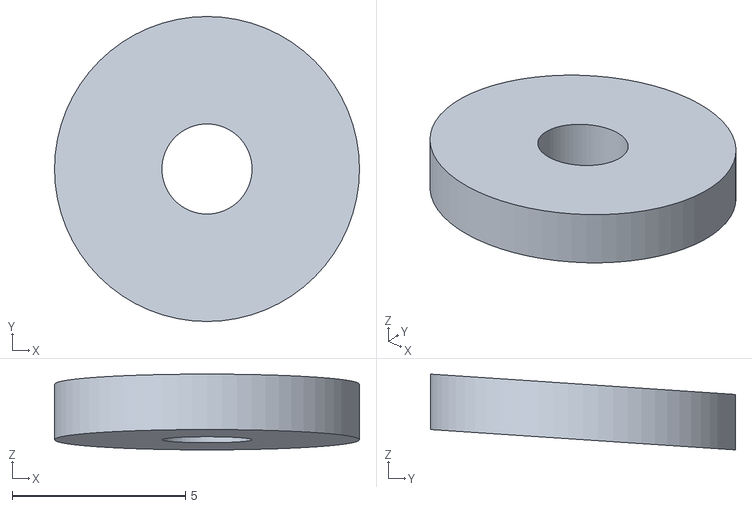
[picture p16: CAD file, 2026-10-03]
hardware/stl/08_Button_stop_collar.stl
8.80 x 8.80 x 2.19

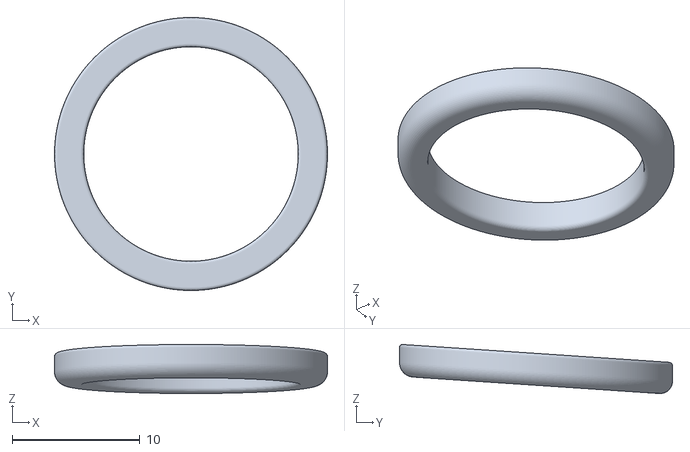
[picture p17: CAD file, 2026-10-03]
hardware/stl/05_Shutter_bezel.stl
21.4 x 21.4 x 3.84

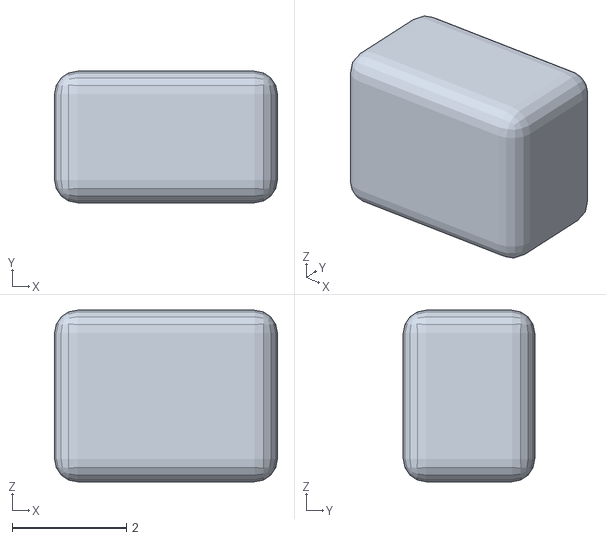
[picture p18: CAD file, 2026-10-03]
hardware/stl/23_Status_window_blank.stl
3.90 x 2.30 x 3.00

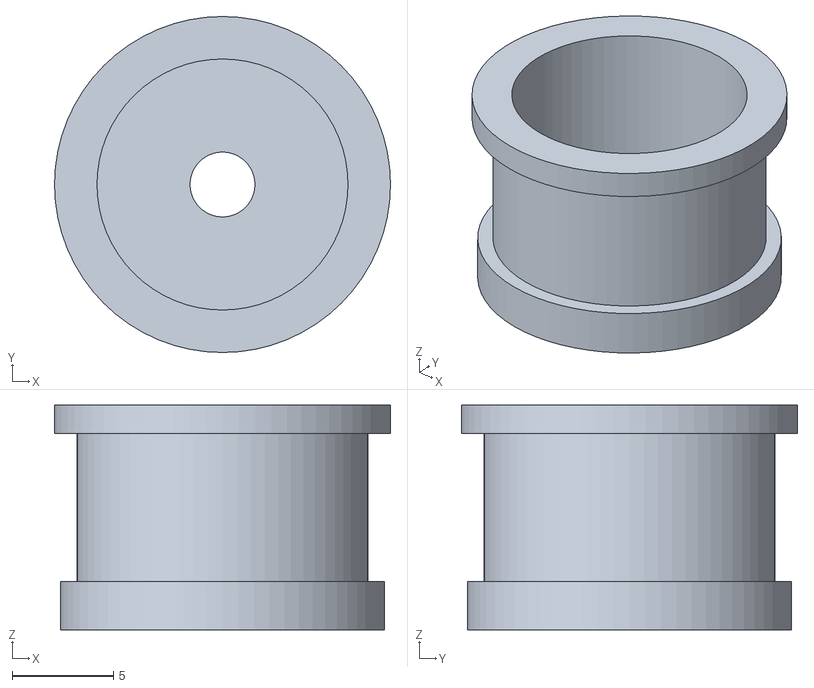
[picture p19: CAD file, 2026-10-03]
hardware/stl/19_Spindle_end_cap.stl
16.6 x 16.6 x 11.1

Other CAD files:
hardware/stl/11_DASHAN_rectangular_badge.stl
hardware/stl/33_LCD183_carrier.stl
hardware/stl/26_Optical_spacer_3mm_39.3_58.7.stl
hardware/stl/18_Paper_spindle.stl
hardware/stl/03_Base_tray.stl
hardware/stl/06_Rounded_shutter_cap.stl
hardware/stl/10_L_inlay_0.stl
hardware/stl/21_Camera_spacer_50.stl
hardware/stl/25_Shutter_switch_holder.stl
hardware/stl/26_Optical_spacer_3mm_39.3_91.3.stl
hardware/stl/26_Optical_spacer_3mm_6.7_58.7.stl
hardware/stl/31_Printer_left_integral.stl

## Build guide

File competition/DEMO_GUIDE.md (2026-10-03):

# 评审演示与证据清单

## 建议的短演示结构

1. **看见物件**：展示机身、顶部嵌入屏幕、实体快门和出纸口。一句话说明它把日常照片变成虚构案件。
2. **按下快门**：拍摄一个无隐私的自有物件。保留观察语音、思考表情和实际等待的一小段，不把剪辑后的时间称作真实模型耗时。
3. **展示案卷**：特写照片、线索、案情与推测，说明事实来自照片，故事是虚构的。声音与纸面要讲同一个案件。
4. **说明实现**：简述 ESP32-S3、Python 后端、模型服务和 3D 打印外壳；明确使用现成模型与 AI 辅助开发。
5. **交代边界**：这是互动创作原型，不是真相识别设备；公开包将提供源码与设计，不提供密钥、私人照片或未经许可音色。

## 三种素材必须区分

- 实机演示：真实快门、上传、模型返回与物理打印，标注实际耗时和使用配置。
- 网页演示：固定案件与预制声音的交互模拟，不包装成现场 AI 调用。
- 故事脚本：用于叙事或拍摄的预设文本，不冒充模型每次必然输出的内容。

## 可核验附件

| 证据 | 当前来源/状态 |
| --- | --- |
| 案件结构与提示词 | `backend/detective_schema.json`、`detective_prompts.py` |
| 后端测试 | 48 项本地测试，详见验证记录；不是实机端到端成功率 |
| 交互模拟 | `demo/`，有字幕、完整出纸与表情 |
| 外壳几何 | `hardware/cad/`、27 个 STL；归档一致性已核验 |
| 快门/音频/屏幕/打印实现 | `firmware/`；首次完整复现需补实物测试记录 |
| 最终 BOM 与螺丝规格 | 部分信息待实测，见 `hardware/BOM.md` |
| 音色与演示照片许可 | 发布前补齐；现有 MP3 只作私有试验归档 |

真实模型对比应记录同一张经授权的照片、输入尺寸、模型 ID、输出字数、重试次数和多轮耗时。没有这些记录时，不宣称固定秒数或稳定胜过某模型。

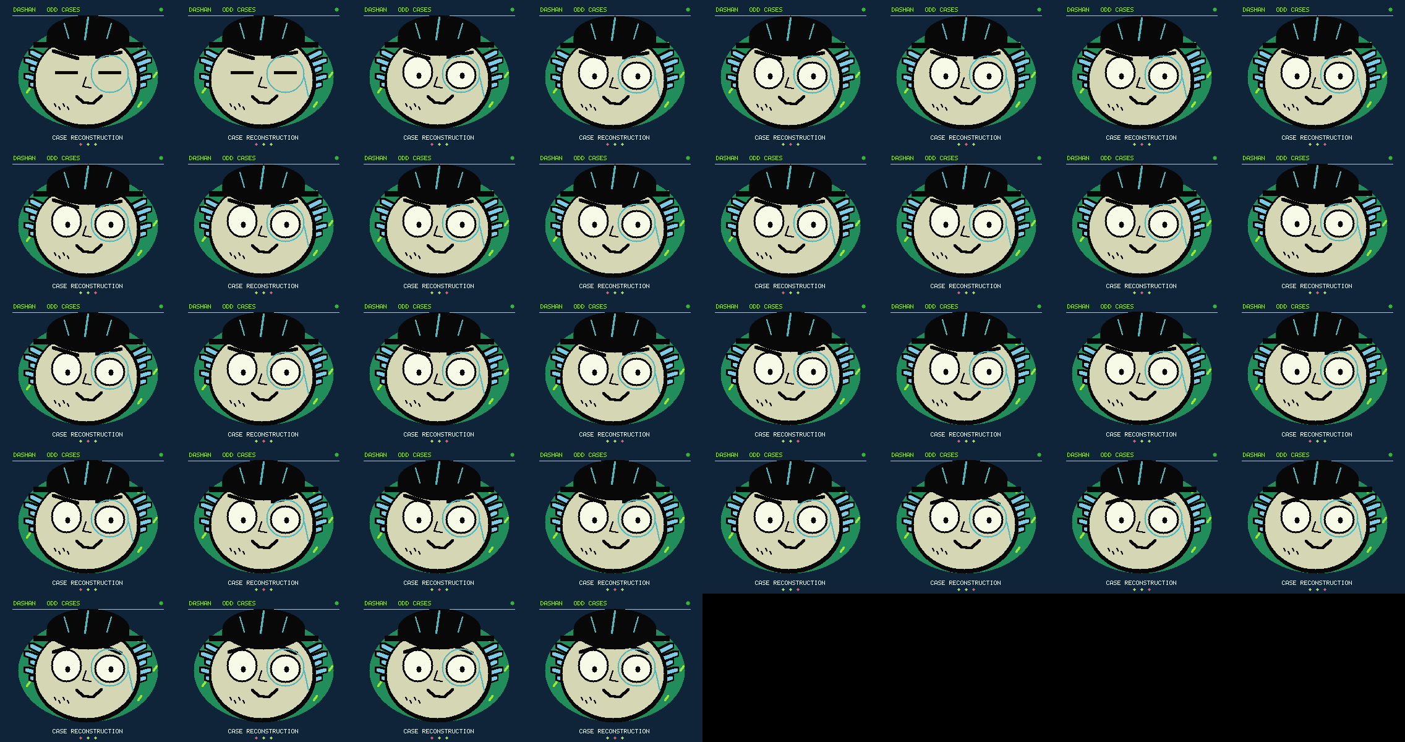
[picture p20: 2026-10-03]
demo/screen-frames/printing-silent.png

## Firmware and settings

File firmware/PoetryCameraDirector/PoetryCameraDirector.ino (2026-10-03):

#include <Arduino.h>
#include <Audio.h>
#include <DNSServer.h>
#include <FFat.h>
#include <HTTPClient.h>
#include <Preferences.h>
#include <Wire.h>
#include <WebServer.h>
#include <WiFi.h>
#include "esp_camera.h"
#include "DetectiveDisplay.h"
#include "es8311.h"

// Waveshare ESP32-S3-CAM-OV5640 pin map from the board documentation.
// PWDN is controlled by the on-board IO expander; -1 keeps the board default.
static constexpr int CAM_D0 = 45, CAM_D1 = 47, CAM_D2 = 48, CAM_D3 = 46;
static constexpr int CAM_D4 = 42, CAM_D5 = 40, CAM_D6 = 39, CAM_D7 = 21;
static constexpr int CAM_PCLK = 41, CAM_VSYNC = 17, CAM_HREF = 18;
static constexpr int CAM_XCLK = 38, CAM_SDA = 8, CAM_SCL = 7;
static constexpr int PRINTER_TX = 43, PRINTER_RX = 44;
static constexpr int SETUP_BUTTON = 0;
static constexpr int AUDIO_MCLK = 10, AUDIO_BCLK = 11, AUDIO_LRCK = 12, AUDIO_DOUT = 14;
// Address verified on the connected Waveshare expansion board (A2:A0=111).
static constexpr uint8_t SHUTTER_MCP_ADDR = 0x27;
static constexpr uint8_t SHUTTER_GPIOB_REG = 0x13;
static constexpr uint32_t SHUTTER_DEBOUNCE_MS = 20;
static constexpr uint32_t PRINTER_BAUD = 9600;

Preferences prefs;
WebServer setupServer(80);
DNSServer dnsServer;
HardwareSerial printer(1);
volatile bool printerBusy = false;
static String activePrintJob;

enum class VoiceStage : uint8_t { Capture, Waiting, LongWait, PrintStart, Error };

struct VoiceCommand {
  VoiceStage stage;
  bool interrupt;
  bool narration;
};

Audio voiceAudio;
ES8311 voiceCodec;
QueueHandle_t voiceQueue = nullptr;
TaskHandle_t voiceTaskHandle = nullptr;
bool voiceReady = false;
bool voiceFsReady = false;
bool voiceCodecReady = false;
bool voiceAmpReady = false;
// Accessed by loop() only as a completion flag; voiceAudio itself remains
// exclusively owned by voiceTask().  0=idle, 1=queued, 2=playing, 3=done,
// 4=failed.
volatile uint8_t caseNarrationState = 0;
volatile bool caseNarrationSawRunning = false;
volatile bool voiceAudioPlaying = false;
volatile bool caseNarrationCancel = false;
extern uint32_t lastHeartbeat;
static void sendHeartbeat();
extern String backendUrl, deviceToken, deviceId;
volatile bool investigationActive = false;
volatile bool synchronizedPrint = false;
// 0 idle, 1 queued, 2 playing, 3 fully drained, 4 failed.
volatile uint8_t reportAnnouncementState = 0;
volatile bool reportAnnouncementSawRunning = false;
volatile uint32_t reportAnnouncementStartedAt = 0;
// Only guard against the decoder's brief startup false-idle window.  The
// actual release condition remains: playback has really run, then stopped,
// and the I2S buffer has drained.
static constexpr uint32_t kReportAnnouncementMinimumMs = 900;
uint32_t voiceTestEnd = 0;
bool voiceTestNarration = false;
uint32_t investigationStarted = 0;
uint32_t nextWaitingVoice = 0;
uint8_t waitingVoiceCount = 0;
uint8_t recentVoices[3] = {};
uint8_t recentVoicePos = 0;
bool shutterReady = false;
bool shutterRawPressed = false;
bool shutterStablePressed = false;
bool shutterArmed = true;
uint32_t shutterChangedAt = 0;
volatile bool standbyRequested = false;
volatile bool standbyDisplayDone = false;
volatile bool standbyVoiceDone = false;
bool standbyActive = false;
bool shutterLongHandled = false;
uint32_t shutterPressedAt = 0;
QueueHandle_t shutterEvents = nullptr;
TaskHandle_t shutterTaskHandle = nullptr;
SemaphoreHandle_t boardI2cMutex = nullptr;
volatile bool shutterSamplingEnabled = false;
static void servicePhysicalShutter();

static void executeJob(const String &json);

static void voiceRange(VoiceStage stage, uint8_t &first, uint8_t &last, const char *&suffix) {
  switch (stage) {
    case VoiceStage::Capture: first = 1; last = 4; suffix = "shutter"; break;
    case VoiceStage::Waiting: first = 5; last = 8; suffix = "wait"; break;
    case VoiceStage::LongWait: first = 5; last = 8; suffix = "wait"; break;
    case VoiceStage::PrintStart: first = 9; last = 12; suffix = "printing"; break;
    default: first = 73; last = 80; suffix = "error"; break;
  }
}

static bool wasRecentlyPlayed(uint8_t number) {
  for (uint8_t recent : recentVoices) if (recent == number) return true;
  return false;
}

static String chooseVoiceFile(VoiceStage stage) {
  if (stage == VoiceStage::PrintStart && FFat.exists("/voice/report.mp3")) return "/voice/report.mp3";
  uint8_t first, last;
  const char *suffix;
  voiceRange(stage, first, last, suffix);
  uint8_t number = first;
  for (uint8_t attempt = 0; attempt < 32; attempt++) {
    number = first + (esp_random() % (last - first + 1));
    if (!wasRecentlyPlayed(number)) break;
  }
  recentVoices[recentVoicePos] = number;
  recentVoicePos = (recentVoicePos + 1) % (sizeof(recentVoices) / sizeof(recentVoices[0]));
  char path[40];
  snprintf(path, sizeof(path), "/voice/%02u_%s.mp3", number, suffix);
  // The installed 12-clip FAT image retained the former 80-slot names:
  // thinking clips start at 13 and report clips at 57. Prefer native names
  // when available; otherwise map the four choices to their installed slots.
  if (!FFat.exists(path)) {
    if (stage == VoiceStage::Waiting || stage == VoiceStage::LongWait)
      snprintf(path, sizeof(path), "/voice/%02u_wait.mp3", 13 + (number - 5));
    else if (stage == VoiceStage::PrintStart)
      snprintf(path, sizeof(path), "/voice/%02u_printing.mp3", 57 + (number - 9));
  }
  return String(path);
}

static void voiceTask(void *) {
  VoiceCommand command;
  VoiceCommand pending{};
  bool hasPending = false;
  uint32_t idleSince = 0;
  uint32_t drainMs = 230;
  for (;;) {
    if(standbyRequested){
      voiceAudio.stopSong();
      hasPending=false;
      xQueueReset(voiceQueue);
      voiceAudioPlaying=false;
      standbyVoiceDone=true;
      while(standbyRequested)vTaskDelay(pdMS_TO_TICKS(20));
      standbyVoiceDone=false;
    }
    if (!hasPending && xQueueReceive(voiceQueue, &command, 0) == pdTRUE) {
      pending = command;
      hasPending = true;
    }
    if (caseNarrationCancel) {
      if (caseNarrationState == 2) {
        voiceAudio.stopSong();
      } else if (hasPending && pending.narration) {
        hasPending = false;
      }
      if (caseNarrationState == 2 || (caseNarrationState == 1 && !hasPending)) {
        caseNarrationState = 4;
        caseNarrationCancel = false;
      }
    }
    // Discard an unstarted thinking line before playback when the result is
    // ready; the line already speaking is allowed to finish naturally.
    if (hasPending && !pending.narration && pending.stage == VoiceStage::Waiting && !investigationActive) hasPending = false;
    const bool drained = !voiceAudio.isRunning() && millis() - idleSince >= drainMs;
    const uint32_t breathMs = hasPending && !pending.narration ?
        (pending.stage == VoiceStage::Waiting ? 400 : pending.stage == VoiceStage::PrintStart ? 1000 : 100) : 100;
    if (hasPending && voiceReady && (pending.interrupt || (drained && millis() - idleSince >= drainMs + breathMs))) {
      if (pending.interrupt) voiceAudio.stopSong();
      String path = pending.narration ? String("/case-narration.mp3") : chooseVoiceFile(pending.stage);
      bool ok = FFat.exists(path) && voiceAudio.connecttoFS(FFat, path.c_str());
      if (ok) idleSince = millis();
      Serial.printf("voice: t=%u %s %s active=%d\n", millis(), ok ? "play" : "open_failed", path.c_str(), investigationActive);
      if (pending.narration) {
        caseNarrationSawRunning = false;
        caseNarrationState = ok ? 2 : 4;
      } else if (pending.stage == VoiceStage::PrintStart) {
        reportAnnouncementSawRunning = false;
        reportAnnouncementStartedAt = ok ? millis() : 0;
        reportAnnouncementState = ok ? 2 : 4;
      }
      hasPending = false;
    }
    if (caseNarrationState == 2 && voiceAudio.isRunning()) caseNarrationSawRunning = true;
    if (caseNarrationState == 2 && caseNarrationSawRunning && !voiceAudio.isRunning() && millis() - idleSince >= drainMs) {
      caseNarrationState = 3;
      // The speaker has drained the final samples. Restore the viewfinder
      // here, without waiting for paper feed or a blocking HTTP completion.
      detectiveDisplaySetState(DetectiveScreenState::Ready);
      Serial.println("display: narration finished -> live preview (printer independent)");
    }
    if (reportAnnouncementState == 2 && voiceAudio.isRunning()) reportAnnouncementSawRunning = true;
    if (reportAnnouncementState == 2 && reportAnnouncementSawRunning &&
        !voiceAudio.isRunning() && millis() - idleSince >= drainMs &&
        millis() - reportAnnouncementStartedAt >= kReportAnnouncementMinimumMs) {
      reportAnnouncementState = 3;
      Serial.printf("voice: report fully finished t=%u elapsed=%u\n", millis(), millis() - reportAnnouncementStartedAt);
    }
    if (voiceReady) voiceAudio.loop();
    voiceAudioPlaying = voiceReady && voiceAudio.isRunning();
    if (voiceAudioPlaying) {
      idleSince = millis();
      uint32_t rate = voiceAudio.getSampleRate();
      if (rate) drainMs = (8192UL * 1000UL + rate - 1) / rate + 40;
    }
    if (investigationActive && voiceReady && !voiceAudioPlaying && !hasPending &&
        uxQueueMessagesWaiting(voiceQueue) == 0 && millis() - idleSince >= drainMs + 400) {
      pending = VoiceCommand{VoiceStage::Waiting, false, false};
      hasPending = true;
    }
    vTaskDelay(pdMS_TO_TICKS(1));
  }
}

static void startVoiceSystem() {
  voiceFsReady = FFat.begin(false);
  if (!voiceFsReady) {
    Serial.println(F("voice: FFat mount failed (upload voice filesystem first)"));
    return;
  }
  // ES8311 and camera share the board I2C bus on GPIO 8/7.
  voiceCodecReady = voiceCodec.begin(CAM_SDA, CAM_SCL, 400000);
  voiceCodecReady &= voiceCodec.setVolume(72);
  voiceCodecReady &= voiceCodec.setBitsPerSample(16);
  // The board's NS4150B speaker amplifier enable is CH32V003 EXIO4.
  // Waveshare's Arduino audio-out example enables it with a HIGH level.
  Wire.beginTransmission(0x24);
  Wire.write(0x02);  // CH32 direction register
  Wire.write(0x77);  // EXIO0/1/2/4/5/6 outputs
  const bool directionOk = Wire.endTransmission() == 0;
  Wire.beginTransmission(0x24);
  Wire.write(0x03);  // CH32 output register
  Wire.write(0x77);  // EXIO4=1 (PA enabled), other required rails high
  const bool outputOk = Wire.endTransmission() == 0;
  voiceAmpReady = directionOk && outputOk;
  voiceReady = voiceCodecReady && voiceAmpReady;
  voiceReady &= voiceAudio.setPinout(AUDIO_BCLK, AUDIO_LRCK, AUDIO_DOUT, AUDIO_MCLK);
  voiceAudio.setVolume(21);  // Decoder-side scale: 0..21.
  Serial.printf("voice: %s codec=%d amp=%d FFat=%u/%u bytes\n",
                voiceReady ? "ready" : "init_failed", voiceCodecReady, voiceAmpReady,
                (unsigned)FFat.usedBytes(), (unsigned)FFat.totalBytes());
  if (!voiceReady) return;
  voiceQueue = xQueueCreate(6, sizeof(VoiceCommand));
  if (!voiceQueue) {
    Serial.println(F("voice: queue allocation failed"));
    return;
  }
  xTaskCreatePinnedToCore(voiceTask, "voice", 12288, nullptr, 2, &voiceTaskHandle, 0);
}

static void requestVoice(VoiceStage stage, bool interrupt = false) {
  if (!voiceQueue || stage == VoiceStage::Error) return;
  VoiceCommand command{stage, interrupt, false};
  if (interrupt) xQueueReset(voiceQueue);
  xQueueSend(voiceQueue, &command, 0);
}

static bool requestCaseNarrationVoice() {
  if (!voiceQueue || !voiceReady || !FFat.exists("/case-narration.mp3")) return false;
  VoiceCommand command{VoiceStage::Waiting, false, true};
  caseNarrationSawRunning = false;
  caseNarrationCancel = false;
  caseNarrationState = 1;
  if (xQueueSend(voiceQueue, &command, 0) != pdTRUE) {
    caseNarrationState = 4;
    return false;
  }
  return true;
}

static bool downloadCaseNarration(const String &jobId, String &detail) {
  static constexpr size_t MAX_AUDIO_BYTES = 1024 * 1024;
  const char *tmpPath = "/case-narration.tmp";
  const char *finalPath = "/case-narration.mp3";
  if (!voiceFsReady) { detail = "voice_fs_not_ready"; return false; }
  FFat.remove(tmpPath);
  HTTPClient http;
  http.begin(backendUrl + "/api/device/jobs/" + jobId + "/audio-data");
  http.setTimeout(60000);
  http.addHeader("X-Dashan-Token", deviceToken);
  http.addHeader("X-Dashan-Device", deviceId);
  int code = http.GET();
  if (code != 200) {
    detail = String("audio_data_http_") + code;
    http.end();
    return false;
  }
  int contentLength = http.getSize();
  if (contentLength > (int)MAX_AUDIO_BYTES) {
    detail = "audio_data_too_large";
    http.end();
    return false;
  }
  File out = FFat.open(tmpPath, FILE_WRITE);
  if (!out) {
    detail = "audio_temp_open_failed";
    http.end();
    return false;
  }
  WiFiClient *stream = http.getStreamPtr();
  uint8_t buffer[1024];
  size_t received = 0;
  uint32_t started = millis();
  bool ok = true;
  while (http.connected() && (contentLength < 0 || received < (size_t)contentLength)) {
    if (millis() - started > 60000) { ok = false; detail = "audio_data_timeout"; break; }
    size_t available = stream->available();
    if (!available) { delay(2); continue; }
    size_t take = min(available, sizeof(buffer));
    if (contentLength >= 0) take = min(take, (size_t)contentLength - received);
    int got = stream->readBytes(buffer, take);
    if (got <= 0 || received + (size_t)got > MAX_AUDIO_BYTES || out.write(buffer, got) != (size_t)got) {
      ok = false; detail = "audio_data_write_failed"; break;
    }
    received += got;
  }
  out.close();
  http.end();
  if (!ok || received == 0 || (contentLength >= 0 && received != (size_t)contentLength)) {
    if (detail.length() == 0) detail = "audio_data_incomplete";
    FFat.remove(tmpPath);
    return false;
  }
  // Only replace the prior case narration after a complete bounded download.
  FFat.remove(finalPath);
  if (!FFat.rename(tmpPath, finalPath)) {
    detail = "audio_final_rename_failed";
    FFat.remove(tmpPath);
    return false;
  }
  detail = String("audio_bytes_") + received;
  return true;
}

static bool playCaseNarration(const String &jobId, String &detail) {
  if (!requestCaseNarrationVoice()) { detail = "narration_queue_failed"; return false; }
  const uint32_t started = millis();
  while (caseNarrationState == 1 || caseNarrationState == 2) {
    detectiveDisplayService(voiceAudioPlaying);
    if (millis() - lastHeartbeat >= 15000UL) {
      lastHeartbeat = millis();
      sendHeartbeat();
    }
    if (millis() - started > 180000UL) {
      caseNarrationCancel = true;
      detail = "narration_timeout";
      return false;
    }
    delay(10); // voiceTask continues on its pinned core
  }
  if (caseNarrationState != 3) { detail = "narration_open_failed"; return false; }
  detail = String("narration_played_") + jobId;
  return true;
}

static void beginInvestigationVoices() {
  investigationActive = true;
  investigationStarted = millis();
  waitingVoiceCount = 0;
  nextWaitingVoice = investigationStarted + 5000;
}

static void finishInvestigationVoices(VoiceStage finalStage) {
  investigationActive = false;
  requestVoice(finalStage, true);
}

static void serviceInvestigationVoices() {
  // The audio task schedules the next line at playback completion, including
  // while the main task is uploading a photo or downloading narration.
}

String wifiSsid, wifiPassword, backendUrl, deviceToken, deviceId;
bool setupMode = false;
bool cameraReady = false;
SemaphoreHandle_t cameraMutex = nullptr;
bool cameraPreviewMode = false;
TaskHandle_t displayTaskHandle = nullptr;
struct CameraGuard {
  CameraGuard(){if(cameraMutex)xSemaphoreTakeRecursive(cameraMutex,portMAX_DELAY);}
  ~CameraGuard(){if(cameraMutex)xSemaphoreGiveRecursive(cameraMutex);}
};
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
void loop() {
  static bool samplerStarted=false;
  if(!samplerStarted){
    samplerStarted=true;
    xTaskCreatePinnedToCore(shutterTask,"shutter",4096,nullptr,2,&shutterTaskHandle,1);
    Serial.printf("shutter: dedicated sampler=%s debounce=20ms\n",shutterTaskHandle?"ready":"fallback");
  }
  shutterSamplingEnabled=true;
  if(!shutterTaskHandle)servicePhysicalShutter();
  processShutterEvent();
  if(standbyActive){
    // USB maintenance wake, also used to verify standby without a key press.
    while(Serial.available())if(Serial.read()=='R')toggleStandby();
    delay(20);return;
  }
  if (voiceTestEnd && (int32_t)(millis() - voiceTestEnd) >= 0) {
    voiceTestEnd = 0;
    investigationActive = false;
    requestVoice(VoiceStage::PrintStart, false);
    Serial.println("voice: sequence test ending");
    if (voiceTestNarration) {
      voiceTestNarration = false;
      String detail;
      bool ok = playCaseNarration("local-sequence-test", detail);
      Serial.printf("voice: full test %s %s\n", ok ? "complete" : "failed", detail.c_str());
    }
  }
  detectiveDisplayService(voiceAudioPlaying);
  // USB serial voice self-test: send 1..5 for capture/wait/long-wait/
  // printing/error.  This remains available for servicing the assembled unit.
  while (Serial.available()) {
    const char command = Serial.read();
    if(command=='S'){toggleStandby();if(standbyActive)return;}
    if (command == 'l') detectiveDisplayRequestSelfTest();
    if (command == 'u') {
      // Maintenance upload: fixed report voice only, no arbitrary file path.
      if (printerBusy || investigationActive || voiceAudioPlaying || caseNarrationState == 1 || caseNarrationState == 2) {
        Serial.println("voice: upload_busy");
        continue;
      }
      Serial.setTimeout(15000);
      Serial.println("voice: upload_ready");
      uint8_t header[4];
      bool ok = Serial.readBytes(header, 4) == 4;
      uint32_t length = ok ? (uint32_t)header[0] | ((uint32_t)header[1]<<8) | ((uint32_t)header[2]<<16) | ((uint32_t)header[3]<<24) : 0;
      ok = ok && length >= 1024 && length <= 256000;
      File output;
      if (ok) { output = FFat.open("/voice/report.tmp", FILE_WRITE); ok = bool(output); }
      uint8_t block[512];
      uint32_t received = 0;
      while (ok && received < length) {
        size_t take = min((uint32_t)sizeof(block), length - received);
        size_t got = Serial.readBytes(block, take);
        ok = got == take && output.write(block, got) == got;
        received += got;
      }
      if (output) output.close();
      if (ok) {
        FFat.remove("/voice/report.previous.mp3");
        if (FFat.exists("/voice/report.mp3")) ok = FFat.rename("/voice/report.mp3", "/voice/report.previous.mp3");
        if (ok) ok = FFat.rename("/voice/report.tmp", "/voice/report.mp3");
      }
      if (!ok) {
        FFat.remove("/voice/report.tmp");
        if (!FFat.exists("/voice/report.mp3") && FFat.exists("/voice/report.previous.mp3")) FFat.rename("/voice/report.previous.mp3", "/voice/report.mp3");
      }
      Serial.printf("voice: upload_%s bytes=%u\n", ok ? "complete" : "failed", received);
      Serial.setTimeout(1000);
    }
    if (command == 'w' || command == 'v') {
      voiceTestNarration = command == 'v';
      requestVoice(VoiceStage::Capture, true);
      beginInvestigationVoices();
      voiceTestEnd = millis() + 20000;
      Serial.println("voice: sequence test started (20s, no camera or printer)");
    }
    if (command == '?') {
      BoardI2cGuard lock;
      Serial.print("shutter: I2C address scan:");
      for(uint8_t address=0x20;address<=0x27;address++){
        Wire.beginTransmission(address);
        if(Wire.endTransmission()==0)Serial.printf(" 0x%02x",address);
      }
      Serial.println();
      uint8_t shutterGpio = 0xFF;
      bool shutterRead = readMcpRegister(SHUTTER_GPIOB_REG, shutterGpio);
      Serial.printf("shutter: ready=%d read=%d address=0x%02x GPIOB=0x%02x PB0=%s armed=%d\n",
                    shutterReady, shutterRead, SHUTTER_MCP_ADDR, shutterGpio,
                    (shutterGpio & 1) ? "released" : "pressed", shutterArmed);
      Wire.beginTransmission(0x18);
      const int codecI2c = Wire.endTransmission();
      Wire.beginTransmission(0x24);
      const int ampI2c = Wire.endTransmission();
      Serial.printf("voice: status fs=%d codec=%d amp=%d queue=%d i2c18=%d i2c24=%d file01=%d used=%u total=%u\n",
                    voiceFsReady, voiceCodecReady, voiceAmpReady, voiceQueue != nullptr,
                    codecI2c, ampI2c,
                    voiceFsReady && FFat.exists("/voice/01_shutter.mp3"),
                    voiceFsReady ? (unsigned)FFat.usedBytes() : 0,
                    voiceFsReady ? (unsigned)FFat.totalBytes() : 0);
    }
    if (command >= '1' && command <= '5') {
      const VoiceStage stages[] = {VoiceStage::Capture, VoiceStage::Waiting,
                                   VoiceStage::LongWait, VoiceStage::PrintStart,
                                   VoiceStage::Error};
      Serial.printf("voice: manual test stage %c\n", command);
      requestVoice(stages[command - '1'], true);
    }
  }
  if (setupMode) {
    dnsServer.processNextRequest(); setupServer.handleClient();
    uint32_t now = millis();
    if (now - lastSetupLog >= 2000) {
      lastSetupLog = now;
      Serial.printf("AP alive: %s clients=%d ip=%s\n", WiFi.softAPSSID().c_str(), WiFi.softAPgetStationNum(), WiFi.softAPIP().toString().c_str());
    }
    delay(2); return;
  }
  if (WiFi.status() != WL_CONNECTED) {
    detectiveDisplaySetConnected(false);
    static uint32_t lastReconnect=0;
    if(millis()-lastReconnect>=10000){lastReconnect=millis();WiFi.reconnect();}
    delay(10);return;
  }
  uint32_t now = millis();
  if(cameraReady && !investigationActive && !voiceAudioPlaying &&
     (caseNarrationState==3 || caseNarrationState==4) &&
     (reportAnnouncementState==3 || reportAnnouncementState==4)){
    detectiveDisplaySetState(DetectiveScreenState::Ready);
  }
  serviceInvestigationVoices();
  if (now - lastHeartbeat >= 15000) { lastHeartbeat = now; sendHeartbeat(); }
  if (now - lastPoll >= (investigationActive ? 500UL : 1500UL)) { lastPoll = now; pollJob(); }
  delay(5);
}

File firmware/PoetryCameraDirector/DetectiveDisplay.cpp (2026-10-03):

#include "DetectiveDisplay.h"

#include <Wire.h>
#include <math.h>
#include "img_converters.h"
#include "driver/spi_master.h"
#include "esp_heap_caps.h"
#include "esp_lcd_panel_io.h"
#include "esp_lcd_panel_ops.h"
#include "esp_lcd_panel_st7789.h"

namespace {
constexpr int W = 284, H = 240;
constexpr int PIN_MOSI = 1, PIN_CLK = 5, PIN_DC = 3, PIN_CS = 6;
constexpr uint8_t IOX = 0x24;
constexpr uint16_t PAPER = 0xDF13, INK = 0x0841, RED = 0xF28D;
constexpr uint16_t GOLD = 0x9F27, MUTED = 0x55B7, BLACK = 0x0000, WHITE = 0xF7DC;
constexpr uint16_t SPACE = 0x1127, SKIN = 0xD6B6, HAIR = 0x7E5C;

esp_lcd_panel_handle_t panel = nullptr;
esp_lcd_panel_io_handle_t panelIo = nullptr;
uint16_t *canvas = nullptr;
uint16_t *dmaStrip = nullptr;
volatile DetectiveScreenState currentState = DetectiveScreenState::Boot;
bool connected = false, ready = false, talkingShown = false;
uint8_t faceVariant = 0;
uint32_t lastFaceChange = 0;
String currentDetail;
SemaphoreHandle_t frameDone = nullptr;
TaskHandle_t displayOwner = nullptr;
volatile bool selfTestRequested = false;
uint32_t lastFrame = 0;
uint8_t *decoded = nullptr;
size_t decodedCapacity = 0;
void rect(int x, int y, int w, int h, uint16_t c);
bool onFrameDone(esp_lcd_panel_io_handle_t, esp_lcd_panel_io_event_data_t *, void *) {
  BaseType_t wake = pdFALSE;
  xSemaphoreGiveFromISR(frameDone, &wake);
  return wake == pdTRUE;
}
bool present() {
  // A full PSRAM frame needs an internal DMA bounce buffer larger than the
  // free heap after audio starts. Reuse a bounded 16-row internal DMA strip.
  for(int y=0;y<H;y+=16){
    int rows=min(16,H-y);
    memcpy(dmaStrip,canvas+y*W,W*rows*2);
    if(esp_lcd_panel_draw_bitmap(panel,0,y,W,y+rows,dmaStrip)!=ESP_OK)return false;
    xSemaphoreTake(frameDone,portMAX_DELAY);
  }
  return true;
}
void oval(int cx,int cy,int rx,int ry,uint16_t color){
  for(int y=-ry;y<=ry;y++){
    int dx=(int)(rx*sqrtf(max(0.0f,1.0f-(float)(y*y)/(ry*ry))));
    rect(cx-dx,cy+y,2*dx+1,1,color);
  }
}

uint16_t swap16(uint16_t c) { return (c << 8) | (c >> 8); }
void px(int x, int y, uint16_t c) { if ((unsigned)x < W && (unsigned)y < H) canvas[y * W + x] = swap16(c); }
void fill(uint16_t c) { uint16_t s = swap16(c); for (int i = 0; i < W * H; ++i) canvas[i] = s; }
void rect(int x, int y, int w, int h, uint16_t c) {
  for (int yy = max(0, y); yy < min(H, y + h); ++yy)
    for (int xx = max(0, x); xx < min(W, x + w); ++xx) px(xx, yy, c);
}
void frame(int x, int y, int w, int h, int t, uint16_t c) {
  rect(x, y, w, t, c); rect(x, y + h - t, w, t, c); rect(x, y, t, h, c); rect(x + w - t, y, t, h, c);
}
void line(int x0, int y0, int x1, int y1, uint16_t c, int thick = 1) {
  int dx = abs(x1-x0), sx = x0<x1?1:-1, dy = -abs(y1-y0), sy = y0<y1?1:-1, e=dx+dy;
  while (true) { rect(x0-thick/2,y0-thick/2,thick,thick,c); if(x0==x1&&y0==y1) break; int e2=2*e; if(e2>=dy){e+=dy;x0+=sx;} if(e2<=dx){e+=dx;y0+=sy;} }
}
void circle(int cx, int cy, int r, uint16_t c, bool solid=false) {
  for (int y=-r; y<=r; ++y) for (int x=-r; x<=r; ++x) {
    int d=x*x+y*y; if (solid ? d<=r*r : (d<=r*r && d>=(r-2)*(r-2))) px(cx+x,cy+y,c);
  }
}

// Compact 5x7 capitals used by the appliance UI.
const uint8_t* glyph(char c) {
  static const uint8_t blank[5]={0,0,0,0,0};
  static const uint8_t nums[10][5]={{62,81,73,69,62},{0,66,127,64,0},{66,97,81,73,70},{33,65,69,75,49},{24,20,18,127,16},{39,69,69,69,57},{60,74,73,73,48},{1,113,9,5,3},{54,73,73,73,54},{6,73,73,41,30}};
  static const uint8_t az[26][5]={
    {126,17,17,17,126},{127,73,73,73,54},{62,65,65,65,34},{127,65,65,34,28},{127,73,73,73,65},{127,9,9,9,1},{62,65,73,73,122},{127,8,8,8,127},{0,65,127,65,0},{32,64,65,63,1},{127,8,20,34,65},{127,64,64,64,64},{127,2,12,2,127},{127,4,8,16,127},{62,65,65,65,62},{127,9,9,9,6},{62,65,81,33,94},{127,9,25,41,70},{70,73,73,73,49},{1,1,127,1,1},{63,64,64,64,63},{31,32,64,32,31},{127,32,24,32,127},{99,20,8,20,99},{3,4,120,4,3},{97,81,73,69,67}};
  if(c>='A'&&c<='Z') return az[c-'A']; if(c>='0'&&c<='9') return nums[c-'0'];
  static const uint8_t dash[5]={8,8,8,8,8}, dot[5]={0,96,96,0,0}, colon[5]={0,54,54,0,0};
  if(c=='-') return dash; if(c=='.') return dot; if(c==':') return colon; return blank;
}
void text(int x,int y,const char*s,uint16_t c,int scale=1) {
  while(*s){ const uint8_t*g=glyph(toupper(*s++)); for(int a=0;a<5;a++) for(int b=0;b<7;b++) if(g[a]&(1<<b)) rect(x+a*scale,y+b*scale,scale,scale,c); x+=6*scale; }
}
int textWidth(const char*s,int scale){return strlen(s)*6*scale-scale;}
void centered(int y,const char*s,uint16_t c,int scale=1){text((W-textWidth(s,scale))/2,y,s,c,scale);}

void drawMagnifier(int x,int y,uint16_t c){circle(x,y,12,c);line(x+9,y+9,x+23,y+23,c,4);}
void drawFace(uint8_t v, bool talking) {
  const uint32_t t=millis();
  const int cx=W/2, cy=119+(int)(2*sinf(t/650.0f));
  const bool thinking=currentState==DetectiveScreenState::Deducing;
  const bool solved=currentState==DetectiveScreenState::Printing;
  const bool blink=t%4300<135;
  // Oversized cut-paper face; a restrained deerstalker identifies the character.
  // Rough, mismatched contours and pin pupils give this original detective
  // a scruffy sci-fi cartoon character rather than a polished emoji face.
  for(int side=-1;side<=1;side+=2){
    for(int i=0;i<5;i++)line(cx+side*68,cy-23+i*12,cx+side*(91+(i%2)*8),cy-35+i*13,INK,10);
    for(int i=0;i<5;i++)line(cx+side*68,cy-23+i*12,cx+side*(91+(i%2)*8),cy-35+i*13,HAIR,5);
  }
  oval(cx-2,cy+12,87,77,INK); oval(cx-3,cy+10,82,72,SKIN);
  oval(cx,cy-62,67,33,INK);
  rect(cx-67,cy-60,134,12,INK);
  line(cx-84,cy-47,cx+84,cy-47,INK,9);
  line(cx,cy-91,cx-5,cy-56,MUTED,3);
  line(cx-38,cy-81,cx-31,cy-57,MUTED,2);
  line(cx+38,cy-81,cx+31,cy-57,MUTED,2);
  const int look=thinking?(int)(6*sinf(t/1150.0f)):2;
  for(int side=-1;side<=1;side+=2){
    const int ex=cx+side*35;
    if(blink) line(ex-16,cy-2,ex+16,cy-2,INK,5);
    else {
      oval(ex,cy+(side<0?-3:2),25,side<0?27:23,INK);
      oval(ex,cy+(side<0?-3:2),22,side<0?24:20,WHITE);
      oval(ex+look,cy+3,4,5,INK);
      if(thinking){rect(ex-22,cy-23,44,12,SKIN);line(ex-21,cy-10,ex+21,cy-13,INK,3);}
    }
    const int tilt=(thinking || v%3==1)?side*7:solved?-side*5:side*3;
    line(ex-21,cy-32-tilt,ex+18,cy-30+tilt,INK,5);
  }
  // Monocle and warm cheek marks remain inside the rounded-panel safe area.
  circle(cx+35,cy,31,MUTED); line(cx+66,cy+6,cx+73,cy+38,MUTED,2);
  line(cx-3,cy+6,cx-8,cy+21,INK,2);line(cx-8,cy+21,cx+5,cy+23,INK,2);
  for(int i=0;i<4;i++){line(cx-54+i*7,cy+49+i%2*5,cx-52+i*7,cy+53+i%2*5,INK,2);}
  if(talking){
    int open=5+(int)(12*fabsf(sinf(t/115.0f)));
    oval(cx+3,cy+43,26,open,INK);
    if(open>10){
      oval(cx+7,cy+49,13,4,RED);
      for(int i=0;i<4;i++)rect(cx-15+i*9,cy+43-open+2,7,5+i%2*2,WHITE);
    }
  } else if(thinking){
    line(cx-14,cy+44,cx+13,cy+40,INK,4);
  } else {
    line(cx-18,cy+37,cx-7,cy+47,INK,4);
    line(cx-7,cy+47,cx+9,cy+48,INK,4);
    line(cx+9,cy+48,cx+22,cy+36,INK,4);
  }
}
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

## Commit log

2026-10-03 Initial privacy-safe detective camera project and interactive demo
2026-10-03 Archive current detective camera with sanitized V33 CAD and restore guides
    [02_Rear_housing.stl, 03_Base_tray.stl, 05_Shutter_bezel.stl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]
2026-10-03 Focus project introduction on the camera and link the online demo
